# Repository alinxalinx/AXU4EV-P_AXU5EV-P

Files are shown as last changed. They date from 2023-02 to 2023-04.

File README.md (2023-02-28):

# Xilinx Zynq UltraScale+MPSoC series development board AXU4EV-P/AXU5EV-P
## Introduction to development board  
### Introduction to development board
In terms of backplane design, we have extended a variety of peripheral interfaces for users, such as one FMC LPC interface, one M.2 SSD SSD interface, one DP interface, one PCIE x2 interface, two SFP+optical fiber interfaces, four USB3.0 interfaces, two gigabit Ethernet interfaces, one HDMI input interface, one HDMI output interface, two UART interfaces, one SD card interface, two CAN bus interfaces 2-way RS485 interface and 1-way MIPI camera interface, etc.
### Key characteristics 
1. 1-way M.2 interface, PCIEx1 (ps), speed 6Gbps
2. 1-channel DP output interface, mini DP (ps), maximum support 4kx2k@30fps output
3. 4-way USB3.0 interface, usb (ps), speed 5.0Gbps, flat USB interface (USB Type A)
4. 2-way Gigabit Ethernet interface, jl2121, 1-way ps, 1-way pl, rgmii interface
5. Two uart to usb, one ps and one pl
6. 2-way PCIE3.0, PCIEx2 high-speed transmission interface, rate 8G Baud
7. 2-way SFP pipeline interface, 12.5Gb/s
8. 1 Micro SD card holder (ps)
9. One channel of hdmi video input interface and one channel of hdmi video output interface, with maximum support 1080P@60Hz resolving power
10. 1 standard FMC LPC expansion port
11. 2-way CAN communication interface (ps)
12. 2-way 485 communication interface (pl)
13. 1 channel mipi interface (pl), 15PIN FPC connector, 2 lane data, 1 pair of clock
14. 1 RTC real-time clock, 32.768KHz passive clock (ps)
15. EEPROM and temperature sensor, one EEPROM 4Kbit (2x256x8bit) (ps), one LM75 temperature chip (ps), with an accuracy of 0.5 degrees
16. 3 led lights, 1 power supply, 1 pl control, 1 ps control
17. 3 keys, 1 reset key RESET and 2 user keys
18. 200mmx110mm
19. 12v/3A

# AXU4EV-P/AXU5EV-P Demo Project
## Description
This is vivado factory demo project for ALINX board.
## Requirement
* Vivado 2020.1
* AXU4EV-P/AXU5EV-P Development Board
## Create Vivado Project
* Download recent release ZIP archive.
* Create new project folder.
* Extract the download ZIP to the new project folder.
* For different development board, please open **\<archive extracted location\>/vivado/auto_create_project/project_info.tcl**
Choose one devicePart and save.

xczu4ev-sfvc784-1-i is for AXU4EV-P  
xczu5ev-sfvc784-2-i is for AXU5EV-P  
```
set devicePart "xczu4ev-sfvc784-1-i"
#set devicePart "xczu5ev-sfvc784-2-i"
set runs_jobs 5
```

There are two methods to create vivado project as below:
### Create Vivado Project in Vivado tcl console
1. Open Vivado software and switch to "**auto_create_project**" path with **cd** command and **Enter**
```
cd \<archive extracted location\>/vivado/auto_create_project
```
2. Type **source ./create_project.tcl** and **Enter**
```
source ./create_project.tcl
```

### Create Vivado Project using bat
1. In "**auto_create_project**" folder, there is "**create_project.bat**", open it in edit mode, and change to your own vivado software installation path. Save and close.
```
CALL E:\XilinxVitis\Vivado\2020.1\bin\vivado.bat -mode batch -source create_project.tcl
PAUSE
```
2. Double click bat file in Windows environment

For more information, please post on the [ALINX Website] (https://www.alinx.com/en).

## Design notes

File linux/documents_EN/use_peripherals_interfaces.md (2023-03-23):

[Back to Home](../)
## Use the interfaces and peripherals on the development board in LINUX

---
- These interfaces and peripherals are available on the development board AXU4EV-P, AXU5EV-P:\
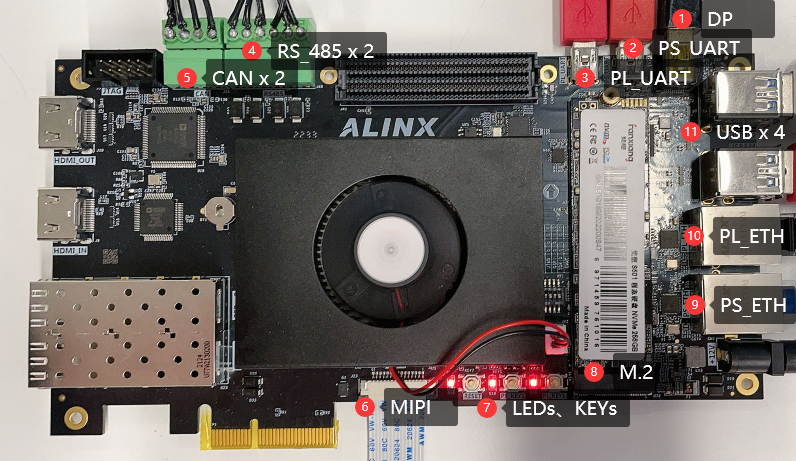
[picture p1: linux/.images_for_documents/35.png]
\
①DP\
②PS_UART\
③PL_UART\
④RS485 x 2\
⑤CAN x 2\
⑥MIPI\
⑦LEDS、KEYS\
⑧M.2\
⑨PS_ETH\
⑩PL_ETH\
⑪USB x 4\
⑫EMMC(Not visible in the figure)\
⑬EEPROM(Not visible in the figure)\
⑭QSPI FLASH(Not visible in the figure)\
⑮RTC(Not visible in the figure)\
⑯LM75(Not visible in the figure)\
PS：In the Linux system on the development board made earlier, I integrated some scripts in *~/shells_for_testing_peripheral_devices/* path which use to test these interfaces and peripherals. You can also refer to these scripts to use these interfaces and peripherals:\
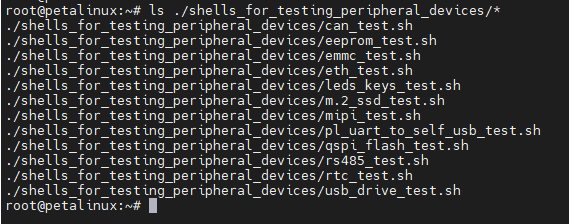
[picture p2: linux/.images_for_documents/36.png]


---
### ①DP
#### 1.1What is DP
DP (DisplayPort) interface is a digital video and audio interface standard used to connect computers, televisions, monitors, audio and other equipment. It is an open standard developed by Video Electronics Standards Association (VESA).\
There are two physical interfaces of DP interface, one is the standard DP interface in rectangular shape, and the other is the Mini DP interface in circular shape. The Mini DP interface is used on our development board.
#### 1.2Using DP in Linux
Connect DP to the display, and you can see the desktop of Macthbox after the system is started :\
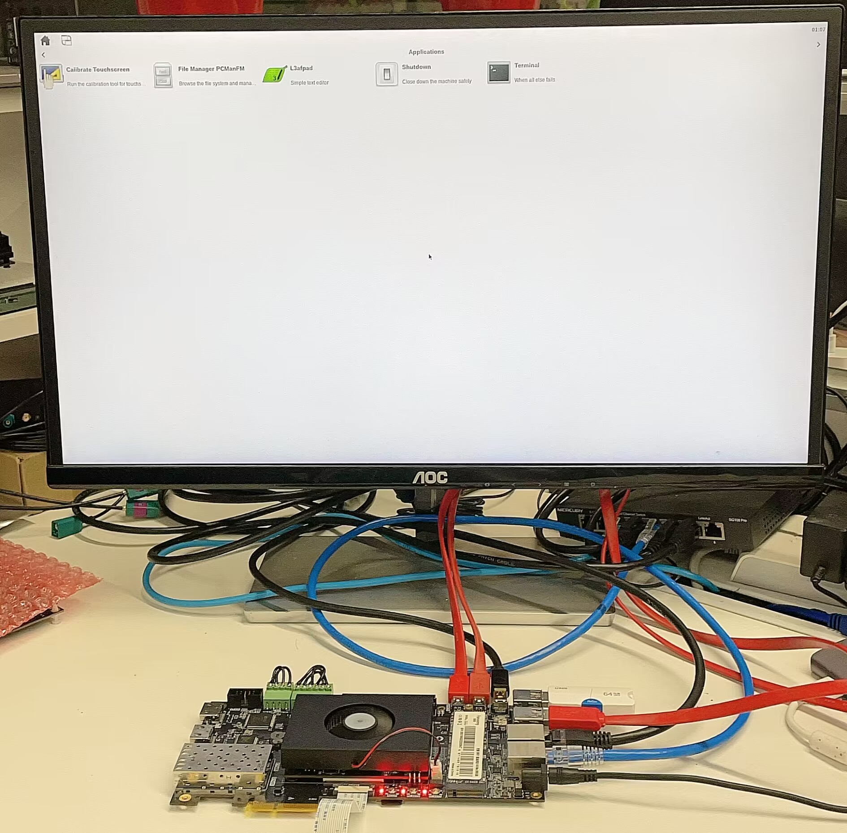
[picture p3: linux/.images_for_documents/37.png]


---
### ②PS_UART
#### 2.1What is PS_UART
UART is a communication protocol, which is called "Universal Asynchronous Receiver/Transmitter". It is a serial communication protocol that can be used to transmit data between microcontrollers, sensors, computer peripheral devices, communication devices, etc.\
UART uses two signal lines for data transmission: one is the data line (TX), which is responsible for sending data; The other is the receiving line (RX), which is responsible for receiving data. UART communication uses asynchronous transmission mode, that is, the clock signals of both sides of the communication are not synchronized, and the start bit, stop bit and parity bit need to be added in the data transmission to ensure the correctness of the data.\
The main advantages of UART are simple, flexible and widely used. Because it is a general protocol that can communicate between different devices, it is widely used in embedded systems and communication fields.\
PS_ UART is the UART interface of ARM end (also called PS end) in ZYNQMP chip.
#### 2.2Using PS_UART in Linux
PS_UART is used as the default terminal console for Linux in our system. Connect PS_UART to the PC(***The driver of CP210x needs to be installed on the PC***) :\
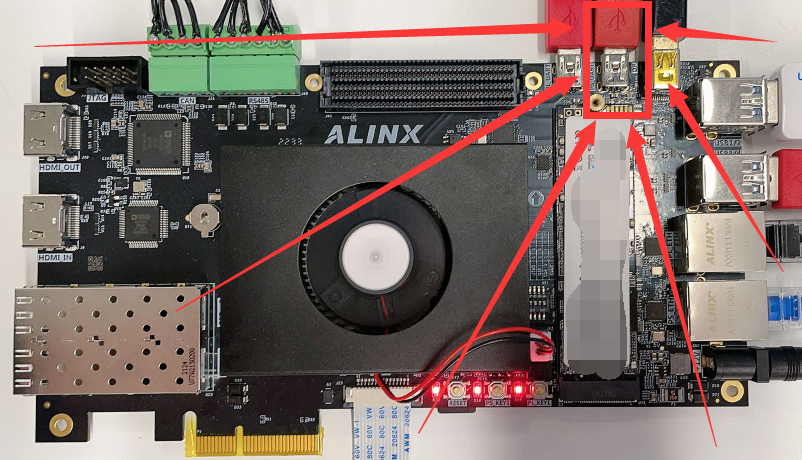
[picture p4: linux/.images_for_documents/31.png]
\
Open the corresponding COM with the serial port tool, set the baud rate to 115200, close the flow control, and click the OK button :\
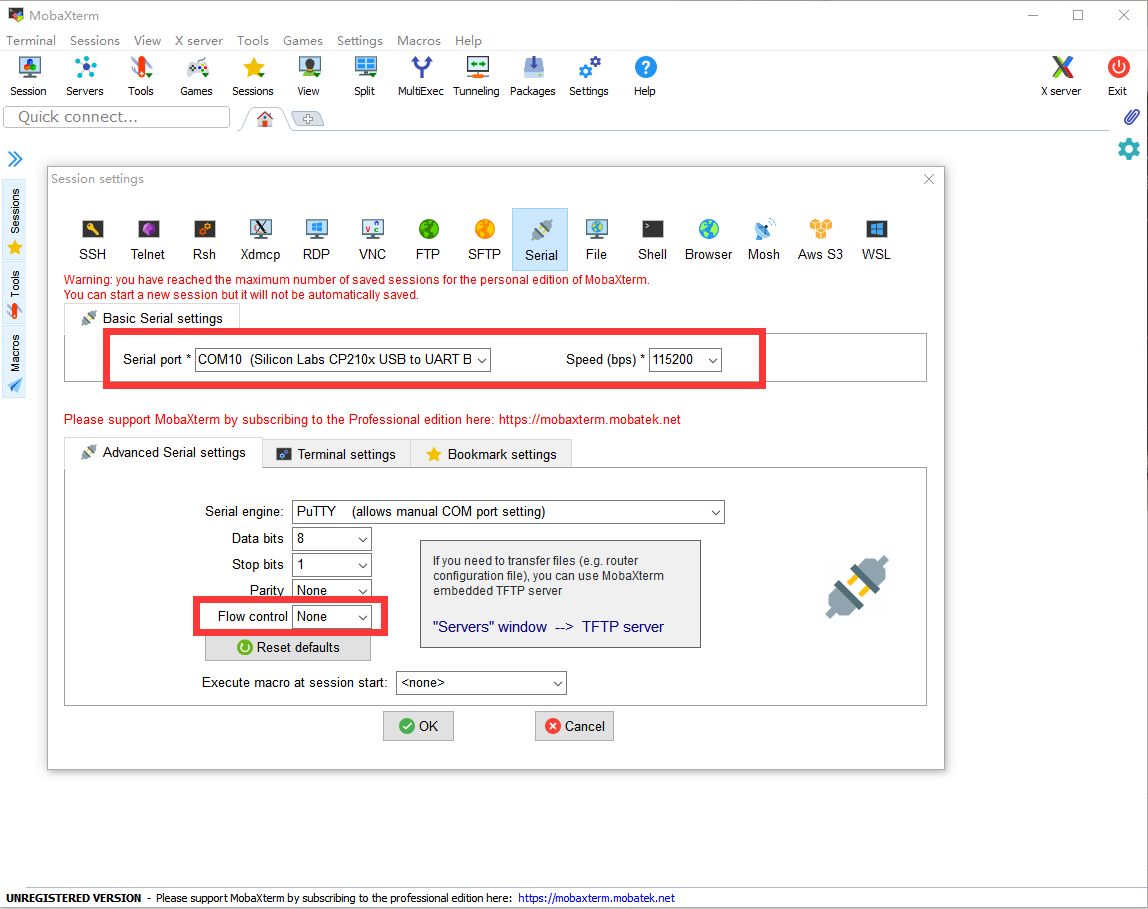
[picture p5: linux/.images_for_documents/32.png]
\
After starting the development board, you can see the print information in the serial port tool :\
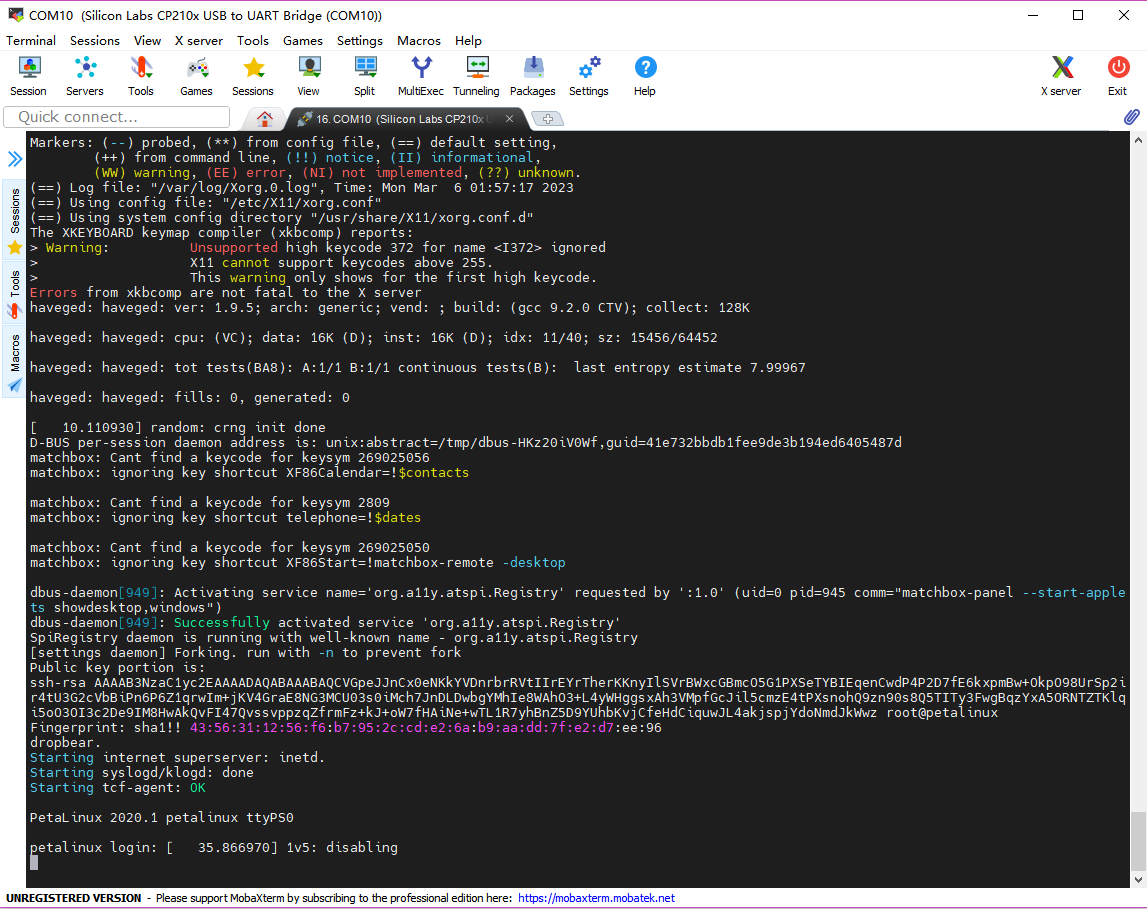
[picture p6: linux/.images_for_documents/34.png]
\
The device of PS_UART in our Linux system is */dev/ttyPS0*. You can use PS_UART interface transmits data by using the `echo "PS_UART test" > /dev/ttyPS0` command :\
\
You can see that the serial port has echo. But PS_UART is used for terminal console, so it is not recommended to operate */dev/ttyPS0*.

---
### ③PL_UART
#### 3.1What isPL_UART
PL_UART is different from PS_UART is the UART interface of the FPGA (also called PL) in the ZYNQMP chip.
#### 3.2Using PL_UART in Linux
Connect the PL_UART to the PC(***The driver of CP210x needs to be installed on the PC*** ).\
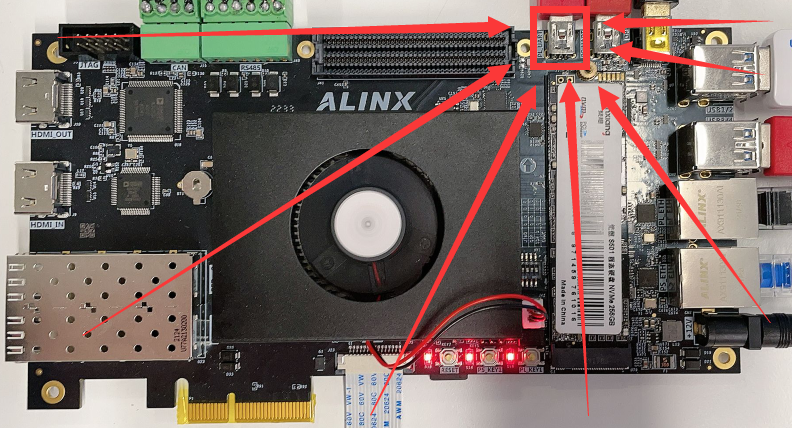
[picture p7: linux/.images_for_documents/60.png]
\
Open the serial port tool, select the corresponding COM, and set the baud rate to 115200 :\
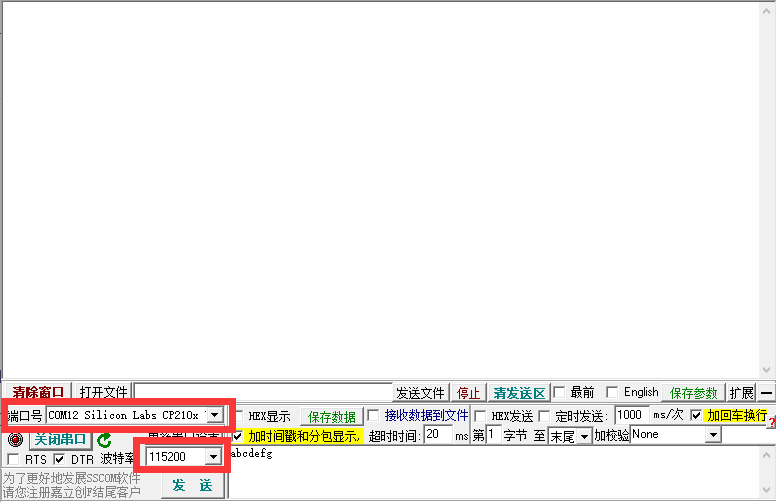
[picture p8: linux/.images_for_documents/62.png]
\
**The number of COM depends on your PC. If your PS_UART and PL_UART are all connected to PC, you can see at least two COM suffixes with *Silicon Labs CP210x USB to UART Bridge* :**\
\
In the Linux system of the development board, the PL_UART device is */dev/ttyPS3*, and the default baud rate is 9600. You can use this command to set the baud rate.\
`stty -F /dev/ttyPS3 ispeed 115200 ospeed 115200 cs8`\
We set it to 115200 corresponding to the setting of the serial port tool, and then use the following command to print the data received by UART :\
`cat /dev/ttyPS3`\
\
Then send some data in the serial port tool, and you can see that the system has received these data :\
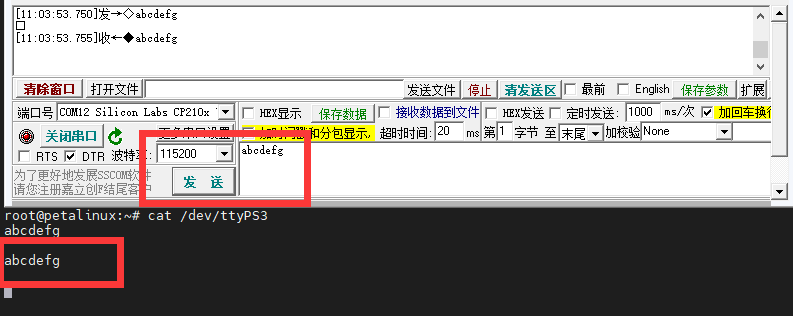
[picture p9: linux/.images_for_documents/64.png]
\
Press *ctrl c* on the keyboard to exit the *cat /dev/ttyPS3* command, and then use the following command to send data \"*PL_UART test*\" to the PC through PL_UART. The serial port tool can receive data:\
`echo "PL_UART test" > /dev/ttyPS3`\
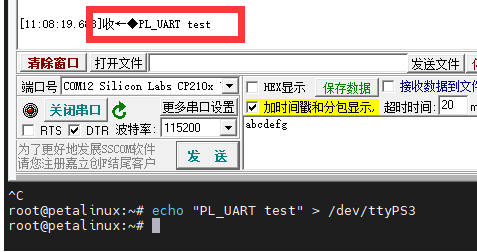
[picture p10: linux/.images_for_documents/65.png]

#### 3.3Use the built-in script in Linux to test PL_UART
Connect the PL_UART to any USB port on the development board :\
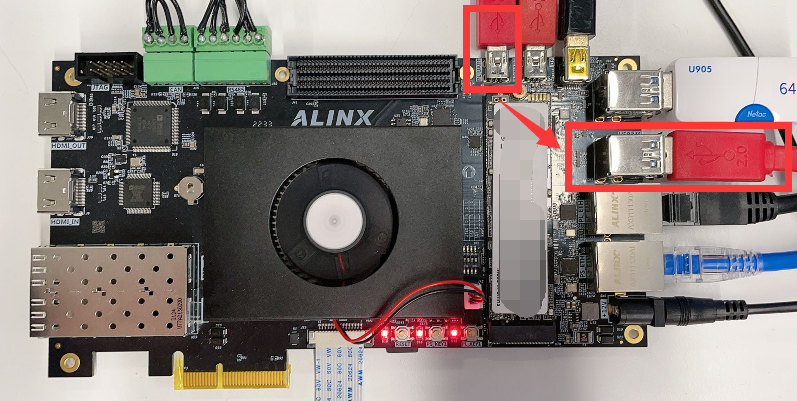
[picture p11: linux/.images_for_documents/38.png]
\
Run the *pl_uart_to_self_usb_test.sh*  script in *~/shells_for_testing_peripheral_devices/* :\
\
Output \"*pl uart to self usb test OK* \" indicates that the UART is intact(ps: this script also verifies that the USB interface is intact).

---
### ④RS485 x 2
#### 4.1What is RS485
RS485 is a common serial communication protocol, also known as EIA-485 protocol. It is a standard formulated by the American Electronic Industry Association (EIA), which is used for data communication between multiple devices. It can transmit data over a long distance. It has the characteristics of high-speed transmission and high reliability.\
RS485 can support point-to-point communication and multi-point communication between multiple devices, that is, a host can communicate with multiple slaves, and can also achieve communication between multiple slaves, to achieve a flexible network topology. The maximum transmission distance of RS485 can reach 1200 meters, and the transmission speed can reach 10 Mbps. In practical applications, the communication rate of 9600 bps or 115200 bps is usually used.\
In our development board, RS485 is a PL-end device, which is realized through FPGA IP.
#### 4.2Using RS485 in Linux
There are two RS485 channels on the development board. The corresponding device files in the system are */dev/ttyS1* and */dev/ttyS2*. RS485 equipment operates in the same way as PS_UART and PL_UART. However, it should be noted that the **baud rate of these two RS485 is fixed at 9600** due to the IP limit at the PL. Setting baud rate of these two RS485 to other values will prevent the device from working properly.
#### 4.3Use the built-in script in Linux to test RS485
Interconnect two RS485 channels：\
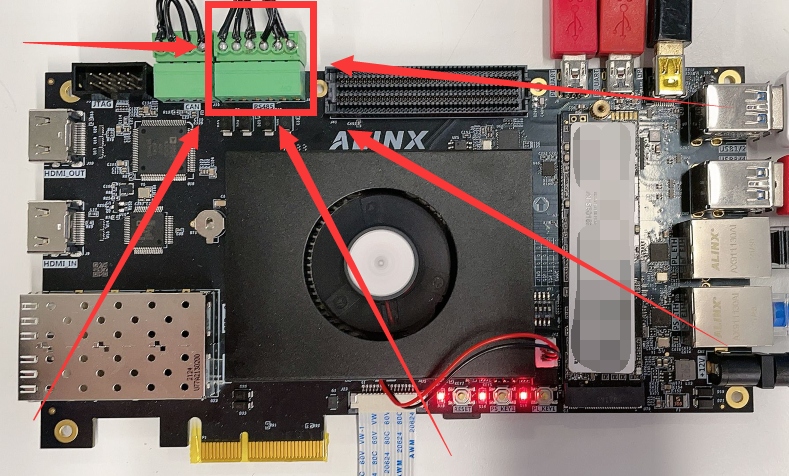
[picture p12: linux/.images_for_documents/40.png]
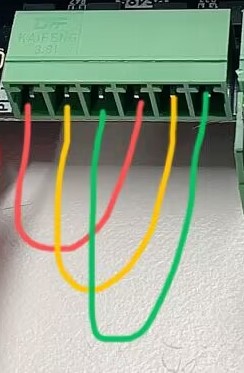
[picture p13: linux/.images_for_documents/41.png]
 \
Run the *rs485_test.sh* script in *~/shells_for_testing_peripheral_devices/* :\
\
As shown in the figure above, the two-way transceiver test is OK, the interface is intact.

---
### ⑤CAN x 2
#### 5.1What is CAN
CAN bus is a serial communication bus, which is a communication protocol widely used in automotive electronics, industrial control and robotics. CAN bus can support data communication between multiple nodes, which is efficient and reliable.\
In the CAN bus, each node can send and receive data, and the nodes are connected through the bus. CAN bus uses differential signal to transmit data, which can reduce the influence of electromagnetic interference and noise and improve the reliability of signal transmission.\
The data frame of CAN bus is divided into standard frame and extended frame. The standard frame contains 11-bit identifier and 8-byte data, while the extended frame contains 29-bit identifier and 8-byte data.\
In Linux system, the control and data transmission of CAN bus can be realized through Socket CAN interface.\
SocketCAN is an open source Linux kernel module, which provides the protocol stack and driver of the CAN bus, and provides a set of interfaces for user-level applications to control and transmit data on the CAN bus. The user can configure the CAN interface and set the parameters of the CAN bus through the ipconfig command.
#### 5.2Using CAN in Linux
Use the command \"`ifconfig - a`\" to see that there are two can channels on the development board, namely *can0* and *can1* :\
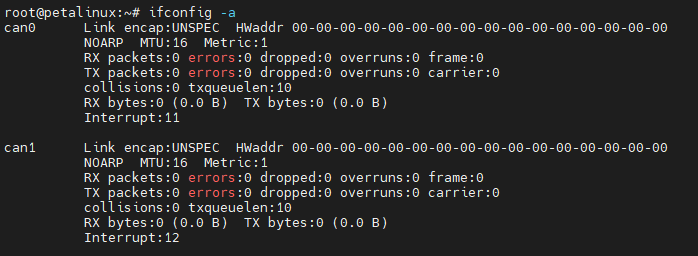
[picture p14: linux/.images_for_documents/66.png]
\
Use this command to set the bitrate of can0 and start can0 :\
`ip link set can0 up type can bitrate 1000000`\
Use this command to receive the data received by can0 :\
`candump can0`\
Use this command to send hex data \"11 22 33 44 55\" with id \"5A1\" via can0 to the CAN bus :\
`cansend can0 5A1#11.2233.4455`
#### 5.3Use the built-in script in Linux to test CAN
Interconnect the two CANs:\
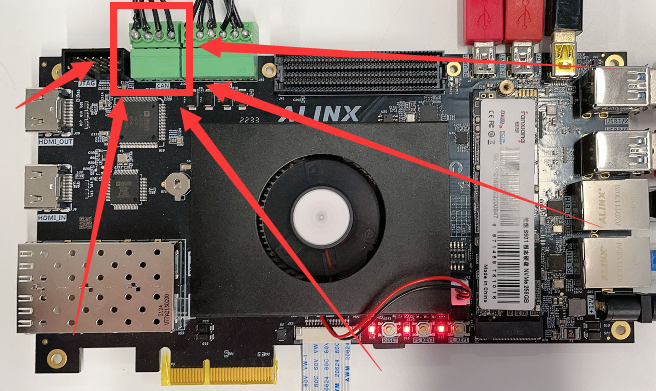
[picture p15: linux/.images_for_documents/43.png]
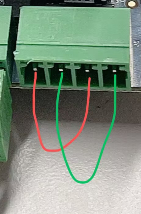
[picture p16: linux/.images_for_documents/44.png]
 \
Run the *can_test.sh* script in *~/shells_for_testing_peripheral_devices/* :\


---
### ⑥MIPI
#### 6.1What is MIPI
MIPI is the abbreviation of Mobile Industry Processor Interface. It is a series of interface standards developed by the MIPI Alliance, an organization created by some major mobile device manufacturers.\
MIPI is mainly committed to defining a series of hardware and software interface standards for mobile devices, including communication interfaces such as cameras, monitors and controllers, to help various parts of mobile devices exchange data and control signals more efficiently. MIPI protocol has the characteristics of high bandwidth, low power consumption, scalability, reliability and security, and is very suitable for modern mobile devices.\
In addition to mobile devices, the application of MIPI has also gradually expanded to other fields, such as automobiles, the Internet of Things, medical devices, etc., and has become one of the important interfaces for communication and control.\
In the current system of our development board, MIPI is designed as an input, which can be connected to the MIPI camera.
#### 6.2Using MIPI in Linux
First, connect a screen to the DP port and connect an OV5640 camera with a MIPI interface to development board(please do not operate with power) :\
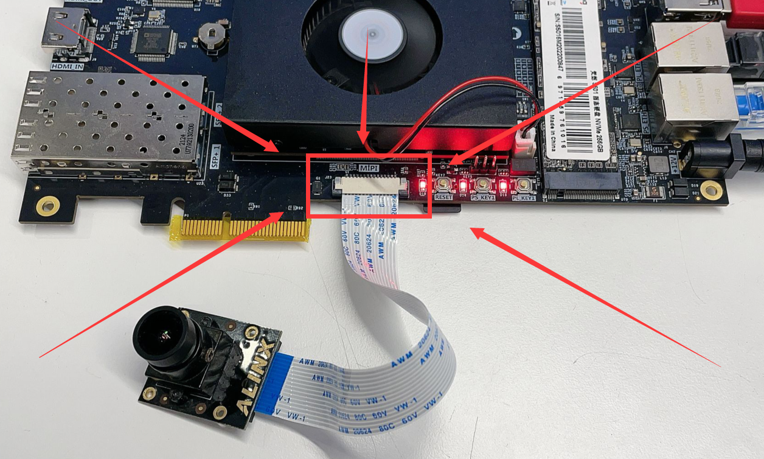
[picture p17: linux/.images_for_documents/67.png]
\
After the system is started and logged in, use the following command：\
`media-ctl -p -d /dev/media0`\
If the node information under the device can be obtained successfully, it means that the i2c connection of the device ov5640 is normal.\
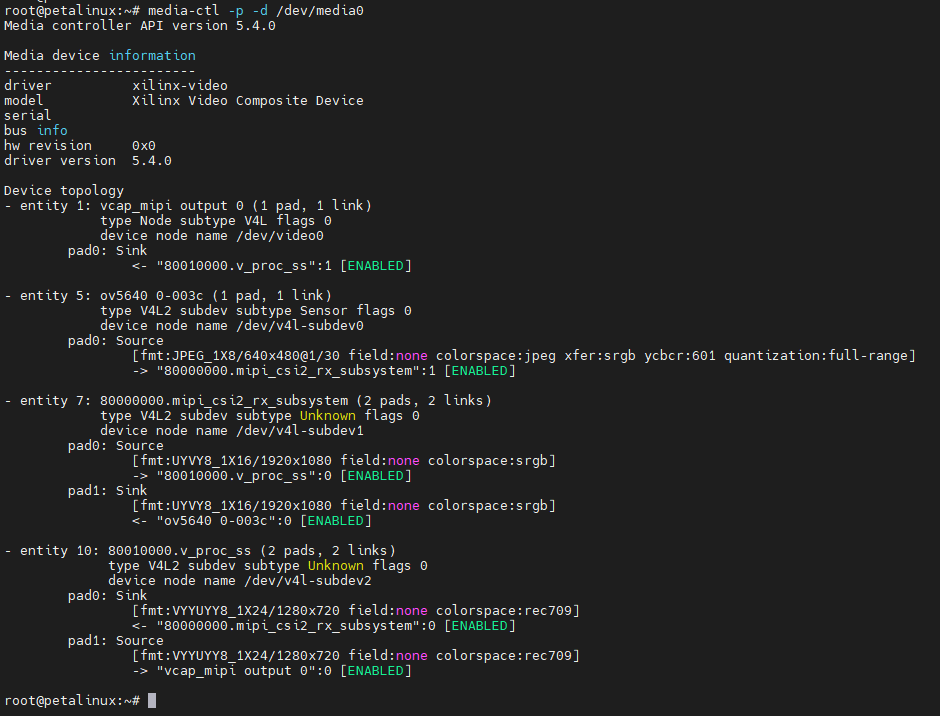
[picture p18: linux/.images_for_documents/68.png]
\
According to the above information, we can obtain the device node name as follows :
```
ov5640 0-003c
80000000.mipi_csi2_rx_subsystem
80010000.v_proc_ss
```
Use the following command to set the camera to 1920x1080, UYVY :
```
media-ctl -V '"ov5640 0-003c":0 [fmt:UYVY8_1X16/1920x1080@1/30 field:none]'
media-ctl -V '"80000000.mipi_csi2_rx_subsystem":0 [fmt:UYVY8_1X16/1920x1080 field:none]'
media-ctl -V '"80000000.mipi_csi2_rx_subsystem":1 [fmt:UYVY8_1X16/1920x1080 field:none]'
media-ctl -V '"80010000.v_proc_ss":0 [fmt:UYVY8_1X16/1920x1080 field:none]'
media-ctl -V '"80010000.v_proc_ss":1 [fmt:UYVY8_1X16/1920x1080 field:none]'
```
Then use the following command to display 1920x1080 camera image on the display :\
`gst-launch-1.0 -e v4l2src device=/dev/video0 ! video/x-raw,format=YUY2,width=1920,height=1080 ! kmssink bus-id=fd4a0000.zynqmp-display fullscreen-overlay=1`
#### 6.3Use the built-in script in Linux to test MIPI
Connect the display to the DP port, connect the MIPI camera to the MIPI port, run the *mipi_test.sh*  script in *~/shells_for_testing_peripheral_devices/* (*ps：Press **ctrl+c** to exit the script.*)：\
\
The camera image is displayed in the screen :\
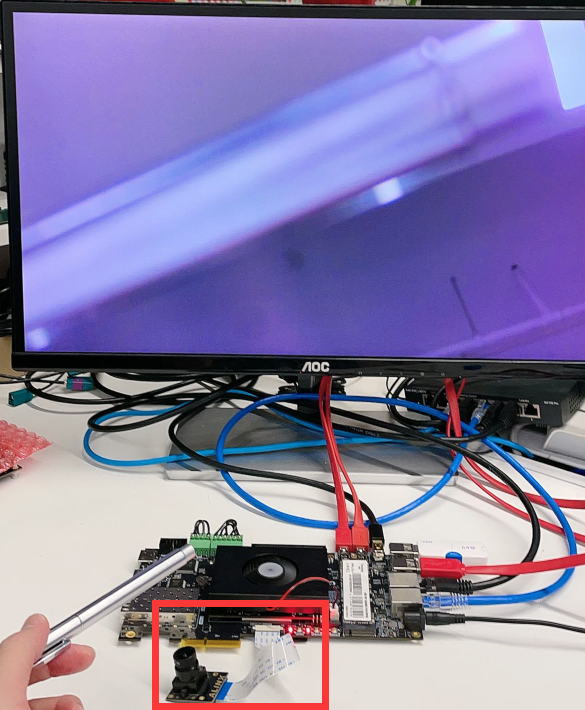
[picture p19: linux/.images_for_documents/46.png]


---
### ⑦LEDS、KEYS
#### 7.1LEDs and KEYs on the development board
There are three groups of LEDs and KEY on the development board. The first group is the POWER indicator and RESET button, the second group is the LED and KEY at the PS, and the third group is the LED and KEY at the PL. The POWER and PS_LED light up after power-on:\
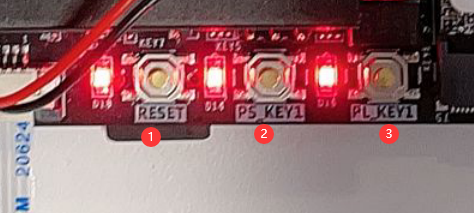
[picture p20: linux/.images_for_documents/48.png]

#### 7.2Using LEDs and KEYs in Linux
Using LEDs and KEYs is actually configuring and using GPIO. In Linux, you only need to know the GPIO number to use the corresponding IO port. The GPIO number of PS_LED is 373, the GPIO number of PS_KEY is 359, the GPIO number of PL_LED is 509, and the GPIO number of PL_KEY is 510.\
The IO corresponding to LED needs to be configured as output. Take PS_LED as an example, the steps to use GPIO output are as follows :
```
#Export the corresponding port
echo 373 >> /sys/class/gpio/export
#Set this port as output
echo out >> /sys/class/gpio/gpio373/direction
#Make this port output high level and light LED
echo 1 >> /sys/class/gpio/gpio373/value
#Make this port output low level and turn off LED
echo 0 >> /sys/class/gpio/gpio373/value
```
The IO corresponding to KEY needs to be configured as output. Taking PL_KEY as an example, the steps to use GPIO input are as follows :
```
#Export the corresponding port
echo 510 >> /sys/class/gpio/export
#Set this port as input
echo in >> /sys/class/gpio/gpio510/direction
#Read the current level state of this IO
cat /sys/class/gpio/gpio510/value
```

#### 7.3Use the built-in script in Linux to test LEDs and KEYs
Run the *leds_keys_test.sh* script in *~/shells_for_testing_peripheral_devices/* (*ps：Press **ctrl+c** to exit the script.*). Then you can use PS_KEY to control the PS_LED to turn on and off, and PL_KEY to control the PS_LED to turn on and off :\


---
### ⑧M.2
#### 8.1What is M.2
M.2 is a high-speed, low-power interface for connecting external devices, such as solid-state hard disk, NVMe devices, etc.\
M.2 Interface consists of PCI Express (PCIe) and SATA (Serial ATA) protocols, which can be used for data transmission, storage and communication. PCIe protocol provides faster transmission speed and more bandwidth, while SATA protocol is more suitable for low-power and high-capacity storage devices.
#### 8.2Use M.2 interface in the system
Take SSD equipment as an example, connect SSD on the M.2 interface of the development board (please do not operate with power) :\
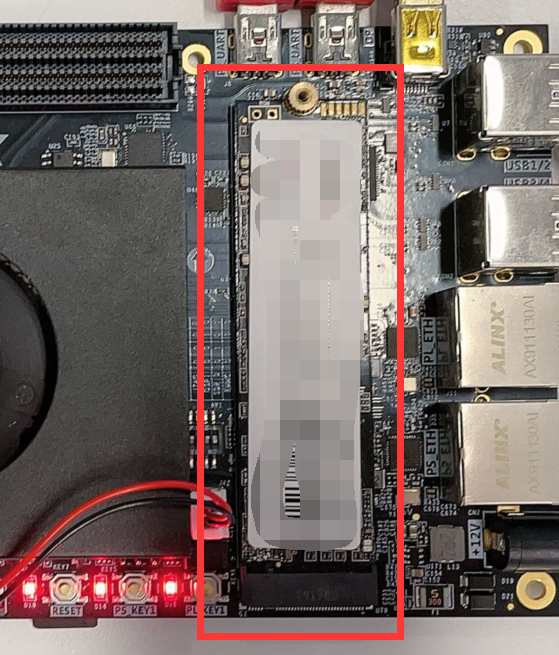
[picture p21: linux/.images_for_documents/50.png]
\
Then start the development board and log in to Linux. If you can find */dev/nvme0n1*, it means that the SSD has been successfully recognized.\
If this SSD has been partitioned, you can also find the device operation files corresponding to partitions like */dev/nvme0n1p1*, */dev/nvme0n1p2* and so on.\
If the SSD does not have a partition or the file system format of the partition is not supported by the Linux system, you can use the **fdisk** tool to allocate the partition, use the **mkfs** tool to set the file system formart, and use the **mount** command to mount it.
For example, the following command will delete the first partition of  */dev/nvme0n1*  and create a new partition, then format the partition into ext4 and mount it to */run/media/nvme0n1p1* :\
```
#Unmount partition
umount /dev/nvme0n1p1
#Delete a partition of /dev/nvme0n1 and create a new partition
echo "d

n
p
1

w
" | fdisk /dev/nvme0n1
#Format the /dev/nvme0n1p1 partition into ext4
echo "y

" | mkfs.ext4 /dev/nvme0n1p1
#mount /dev/nvme0n1p1 on /run/media/nvme0n1p1
mount /dev/nvme0n1p1 /run/media/nvme0n1p1
```
After mounting, you can operate on files in the mounted path, and these files will eventually be saved in the SSD.
#### 8.3Use the built-in script in Linux to test M.2 SSD
Run the *m.2_ssd_test.sh*  script in *~/shells_for_testing_peripheral_devices/* :\
\
Different information will be printed according to the usage of your SSD, but as long as the M.2 interface and SSD are intact, \"*ssd read write OK* \" will be output.

---
### ⑨PS_ETH
#### 9.1What is ETH
In the Linux operating system, \"ETH\" usually refers to the network interface device, which is the hardware device used to communicate between the computer and the network. In Linux, you can use the *ifconfig* command to manage and configure network interface devices. The development board and other network devices can be connected in the same network through the ETH interface for data transmission.\
In the Ethernet protocol, each device is assigned a unique MAC address for identification and communication in the network. When computers send data through network interface devices, they will be encapsulated in Ethernet frames and routed and transmitted using MAC addresses.\
The PS_ETH on the development board is the ETH on the PS side, and the PS_ETH is the ETH on the PL side implemented by IP, but their use methods are the same in the system.
#### 9.2Using ETH in Linux
Connect PS_ETH and PL_ETH (such as through network router or network switch) to the LAN :\
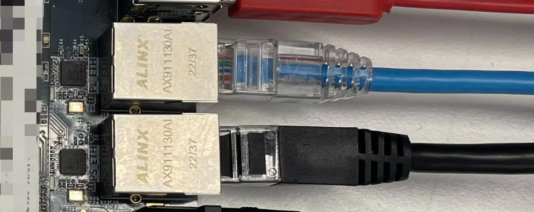
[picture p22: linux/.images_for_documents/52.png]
\
Then power on the development board, log in to the system, and use *ifconfig* to view the current ETH status :\
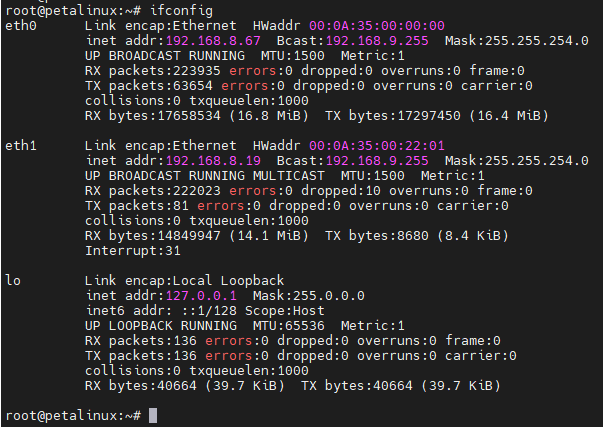
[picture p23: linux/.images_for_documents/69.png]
\
If your router or switch supports DHCP, both eth0 and eth1 will be automatically connected and be assigned an IP address.\
If no IP address is assigned, you need to use the following command to assign it manually, for example :\
`ifconfig eth0 192.168.8.67`\
The *ifconfig* command can also be used to set the subnet mask; If the MAC address needs to be modified, */etc/network/interfaces* needs to be modified; If you want to set the gateway, you need to use command **route**; If you need to modify DNS, you need to modify */etc/resolv.conf*. The relevant configuration will not be detailed, generally, as long as you connect to the LAN through the network cable, you can use eth0 directly after the system is powered on.\
If you want to use eth1, you need to set the default gateway of eth1. The address of the gateway depends on your LAN. If your eth1 and eth0 are connected to the same segment of the same LAN, you can refer to the settings of eth0, for example :
```
#Use route to view the gateway of eth0 first
route
#Set the default gateway of eth1 to be the same as eth0. For example the above route command shows that the default gateway of eth0 is 192.168.8.1
route add default gw 192.168.8.1 eth1
#Use the route command to check and confirm the default gateway of eth1
route
```
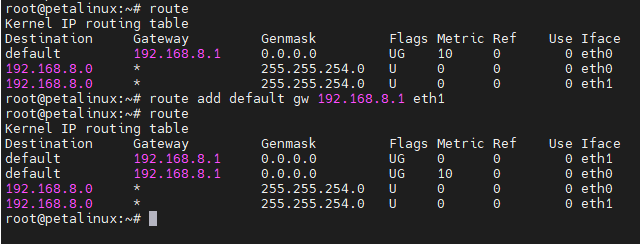
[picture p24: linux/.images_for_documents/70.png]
\
You can use the **ping** command to test the network connection and disconnection, set the number of pings through the **-c** parameter, and select the network interface through the **-I**(uppercase i) parameter :\
`ping -c 1 -I eth1 www.baidu.com`\

#### 9.3Use the built-in script in Linux to test ETH
Run the *eth_test.sh*  script in *~/shells_for_testing_peripheral_devices/*. This script can be followed by a parameter, that is, the address you want to ping. For example, here I ping www.baidu.com. If no parameter is added, the default is ping *www.google.com* :\
\
Finally, the result of the ping and the speed of the network interface link will be print.

---
### ⑩PL_ETH
**See ⑨PS_ETH**.

---
### ⑪USB x 4
#### 11.1What is USB
USB is the abbreviation of Universal Serial Bus. It is a universal data transmission standard used to connect computers or other devices with other devices, including printers, keyboards, mice, scanners, digital cameras, mobile devices and other external devices.\
With the continuous development of technology, the version of USB is also constantly updated. USB 1.0 is the earliest version and the transmission speed is very slow, but with the introduction of USB 2.0, the transmission speed has been significantly improved. USB 3.0 and USB 3.1 are faster versions, providing higher transmission speed and more power. At the same time, USB can also support different data transmission protocols, including HID (human interface device), audio, video and storage devices.\
There are four USB3.0 interfaces on our development board.
#### 11.2Using USB on Linux systems
In fact, common USB devices can be used directly on this system. For example, the mouse and keyboard can be used directly with the desktop. If you use the storage tools such as USB flash disk, you need to pay attention to the partition and file system format. You can refer to the partition and format method of SSD in **⑧M.2**. After the USB flash disk is connected to the system, the device operation files are generally */dev/sda1*, */dev/sda2*, etc.
#### 11.3Use the built-in script in Linux to test USB Drive
Run the *usb_drive_test.sh*  script in *~/shells_for_testing_peripheral_devices/* ( *ps：This system does not support the NTFS file system, so the USB flash drive of the NTFS partition cannot be used directly* ) :\


---
### ⑫EMMC
#### 12.1What is EMMC
EMMC (Embedded MultiMediaCard) is a storage device widely used by embedded devices. It integrates flash memory chip, controller, host interface and flash memory management software into a small package. With its small size, low power consumption and high cost performance, eMMC is a common choice in embedded device storage solutions.\
EMMC is mainly used in mobile devices (such as smart phones, tablets, digital cameras, etc.) and embedded devices in automotive, industrial control and other fields. It provides a high-speed and reliable storage solution, supports fast startup and data reading and writing, and can store operating system, application programs, media files and other data.\
An 8G EMMC is integrated on our development board.
#### 12.2Using EMMC on Linux
The operation file of EMMC in Linux system is */dev/mmcblk0*. The use method is similar to that of SSD in **⑧M.2** : set the partition, format the partition, and finally mount the partition. for example :
```
#Unmount partition
umount /dev/mmcblk0p1
#Delete a partition of /dev/mmcblk0 and create a new partition
echo "d

n
p
1

w
" | fdisk /dev/mmcblk0
#Format the /dev/mmcblk0p1 partition into ext4 format
echo "y

" | mkfs.ext4 /dev/mmcblk0p1
#mount /dev/mmcblk0p1 on /media/sd-mmcblk0p1
mount /dev/mmcblk0p1 /media/sd-mmcblk0p1
```
After mounting, you can operate on files in the mounted path, and these files will eventually be saved in EMMC.
#### 12.3Use the built-in script in Linux to test EMMC
Run the *emmc_test.sh* script in *~/shells_for_testing_peripheral_devices/*  :\


---
### ⑬EEPROM
#### 13.1What is EEPROM
EEPROM is a non-volatile memory (NVM), which is an improved version of the electrically erasable programmable read-only memory (EPROM). EEPROM can be erased and programmed by electronic signals.\
EEPROM is usually used to store a small amount of data, such as configuration information on the chip, product serial number, encryption key, etc. In some electronic devices, EEPROM can also be used to store user settings and personal data.\
Compared with flash memory, EEPROM has faster reading speed and higher durability, but smaller capacity. Compared with DRAM, EEPROM has longer data retention time, but slower write speed.
#### 13.2Using EEPROM on Linux
The operating file of eeprom in the system is */sys/bus/i2c/devices/1-0050/eeprom*.\
Use the following command to write data to eeprom :\
`echo -e "test e2prom\n" > /sys/bus/i2c/devices/1-0050/eeprom`\
Use the following command to view the contents of eeprom :\
`cat /sys/bus/i2c/devices/1-0050/eeprom`\

#### 13.3Use the built-in script in Linux to test EEPROM
Run the *eeprom_test.sh* script in *~/shells_for_testing_peripheral_devices/*  :\


---
### ⑭QSPI FLASH
#### 14.1What is QSPI FLASH
Flash is a kind of high-speed flash memory, which is often used in embedded systems and other applications to store program code, configuration data and other information.\
QSPI Flash is a flash chip based on SPI interface. It communicates through four parallel data lines (quad interfaces). Compared with traditional SPI Flash, it can achieve faster data transmission speed, usually up to tens of MHz. The capacity of QSPI Flash is usually between a few megabytes and tens of megabytes.\
QSPI Flash has many advantages, including fast read and write speed, low power consumption, erasability, easy integration and use, etc. In addition, it can be programmed and erased by software without any external equipment or signal line.
#### 14.2Using QSPI FLASH on Linux systems
In the current Linux system, QSPI FLASH is used to store the environment variables of u-boot. If you modify the environment variables of u-boot, you need to be careful when operating QSPI FLASH.
The operation file of QSPI FLASH in the system is */dev/mtd0*.
The FLASH device needs to be erased before writing. Use the following command to erase the first sector of QSPI FLASH :\
`flash_erase /dev/mtd0 0 1`\
*/dev/mtd0* is a block device. You can use the **dd** command to read or write files to */dev/mtd0*.\
Write the file to */dev/mtd0 with the following command* :
```
touch /home/root/.qspiflashwrite
echo "qspiflash test" > /home/root/.qspiflashwrite
dd of=/dev/mtd0 if=/home/root/.qspiflashwrite bs=4096 count=1
```
Use the following command to read data from */dev/mtd0* to a file :
```
touch /home/root/.qspiflashread
dd if=/dev/mtd0 of=/home/root/.qspiflashread  bs=4096 count=1
```
#### 14.3Use the built-in script in Linux to test QSPI FLASH
Run the *qspi_flash_test.sh* script in *~/shells_for_testing_peripheral_devices/*  :\


---
### ⑮RTC
#### 15.1What is RTC
The Real Time Clock (RTC) unit provides an accurate time reference for the entire system and application software.
#### 15.2Using RTC on Linux systems
In our Linux system, the device operation file of RTC is */dev/rtc0*. You can use the **hwclock** command to read and write */dev/rtc0*. For example:
```
#Set the system time to "2023-03-01 10:30:00"
date --set="2023-03-01 10:30:00"
#Write the system time to/dev/rtc0
hwclock -f /dev/rtc0 -w
#Update the system time with the time in /dev/rtc0
hwclock -f /dev/rtc0 -r
```

#### 15.3Use the built-in script in Linux to test RTC
Run the *rtc_test.sh* script in *~/shells_for_testing_peripheral_devices/* :\


---
### ⑯LM75
#### 16.1What is LM75
LM75 is a digital temperature sensor chip produced by Texas Instruments. It can measure the ambient temperature and communicate with other devices through I2C bus. It is a digital temperature sensor chip with stable performance, high accuracy and good reliability.
#### 16.2Using LM75 on Linux systems
The temperature value collected by LM75 can be obtained by directly reading */sys/bus/i2c/devices/1-0048/hwmon/hwmon0/temp1_input* in Linux, **the unit of this data is m°C**:\
`cat /sys/bus/i2c/devices/1-0048/hwmon/hwmon0/temp1_input`\
\
The temperature read here is 31750m°C, equal to 31.75°C.

---
---
- Visit [ALINX official website](https://www.alinx.com) for more information.

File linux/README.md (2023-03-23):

# Run Linux on Series Development Boards : AXU4EV-P, AXU5EV-P / 在系列开发板：AXU4EV-P、AXU5EV-P上使用Linux
---
---
## Content in this path / 本路径中的内容 
	│
	└─── linux
		│
		├── hardware
		│	│
		│	├── AXU4EV-P
		│	│	│
		│	│	└─ design_1_wrapper.xsa	
		│	│
		│	└── AXU5EV-P
		│		│	
		│	 	└─ design_1_wrapper.xsa	
		│
		├── petalinux
		│
		├── documents_EN
		│	│
		│	├──  make_sd_for_runnging_linux.md	
		│	│
		│	├──  use_petalinux_to_make_linux.md	
		│	│
		│	└──  use_peripherals_interfaces.md
		│
		├── documents_CN
		│	│
		│	├──  make_sd_for_runnging_linux.md	
		│	│
		│	├──  use_petalinux_to_make_linux.md
		│	│
		│	└──  use_peripherals_interfaces.md
		│
		├── auto_config_petalinux_hardware.sh
		│
		├── set_offline_sstate_and_downloads.sh
		│
		└── README.md
---
---
## Documentation Guidelines
- If you want to quickly start a Linux on the development board, please refer to [make_sd_for_runnging_linux.md](./documents_EN/make_sd_for_runnging_linux.md).
- If you want to use Petalinux tool to configure the petalinux project we provide, please refer to [use_petalinux_to_make_linux.md](./documents_EN/use_petalinux_to_make_linux.md).
- If you have successfully started Linux on the development board, and now want to know what interfaces are on the development board and how to use them, please refer to [use_peripherals_interfaces.md](./documents_EN/use_peripherals_interfaces.md).
## 文档指引
- 如果你想快速在开发板上启动Linux，请参考[make_sd_for_runnging_linux.md](./documents_CN/make_sd_for_runnging_linux.md)。
- 如果你想用Petalinux工具来配置我们提供的petalinux工程，请参考[use_petalinux_to_make_linux.md](./documents_CN/use_petalinux_to_make_linux.md)。
- 如果你已经成功在开发板上启动了Linux，现在想知道开发板上有哪些接口以及如何使用，请参考[use_peripherals_interfaces.md](./documents_CN/use_peripherals_interfaces.md)。
---
---
- Visit [ALINX Official Website](https://www.alinx.com) for more information.
- 访问[ALINX官方网站](https://www.alinx.com)以获取更多信息。

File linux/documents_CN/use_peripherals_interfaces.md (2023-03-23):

[返回首页](../)
## 在LINUX中使用开发板上的接口和外设

---
- AXU4EV-P、AXU5EV-P开发板上有这些接口和外设：\
\
①DP\
②PS_UART\
③PL_UART\
④RS485 x 2\
⑤CAN x 2\
⑥MIPI\
⑦LEDS、KEYS\
⑧M.2\
⑨PS_ETH\
⑩PL_ETH\
⑪USB x 4\
⑫EMMC(图中不可见)\
⑬EEPROM(图中不可见)\
⑭QSPI FLASH(图中不可见)\
⑮RTC(图中不可见)\
⑯LM75(图中不可见)\
PS：在前面制作的开发板上的Linux系统中，我集成了一些脚本在 *~/shells_for_testing_peripheral_devices/* 路径中用于测试这些接口和外设，你也可以参考这些脚本来使用这些接口和外设：\


---
### ①DP
#### 1.1什么是DP
DP (DisplayPort) 接口是一种数字视频和音频接口标准，用于连接计算机、电视、显示器、音响等设备。它是一种开放标准，由 Video Electronics Standards Association (VESA) 组织制定。\
DP 接口的物理接口有两种，一种是矩形形状的标准 DP 接口，另一种是圆形形状的 Mini DP 接口。我们的开发板上使用的就是Mini DP接口。
#### 1.2在Linux中使用DP
把DP连接到显示器上即可，系统启动后可以看到Macthbox的桌面：\

### ②PS_UART
#### 2.1什么是PS_UART
UART是一种通信协议，全称为“通用异步收发传输器”（Universal Asynchronous Receiver/Transmitter）。它是一种串行通信协议，可以用于在微控制器、传感器、电脑周边设备、通信设备等之间传输数据。\
UART使用两根信号线来进行数据传输：一根是数据线（TX），负责发送数据；另一根是接收线（RX），负责接收数据。UART通信使用异步传输方式，也就是说，通信双方的时钟信号不同步，需要在数据传输中加入起始位、停止位和奇偶校验位来保证数据的正确性。\
UART的主要优点是简单、灵活和广泛使用。由于它是一种通用协议，可以在各种不同的设备之间进行通信，因此在嵌入式系统和通信领域中应用广泛。\
PS_UART是ZYNQMP芯片中ARM端(也叫做PS端)的UART接口。
#### 2.2在Linux中使用PS_UART
PS_UART在我们制作的系统中用于Linux的默认终端窗口，把PS_UART连接到PC(***PC上需要安装CP210x的驱动***)：\
\
用串口工具打开对应的COM，设置波特率设置为115200，关闭流控制，点击OK按钮：\
\
启动开发板后可以看到串口工具中打印信息：\
\
PS_UART在我们制作的Linux系统中的设备是 */dev/ttyPS0* ，使用`echo "PS_UART test" > /dev/ttyPS0`命令可以通过PS_UART接口传输数据：\
\
可以看到串口有回显，但是PS_UART被用于终端窗口，因此不建议对 */dev/ttyPS0* 进行操作。

---
### ③PL_UART
#### 3.1什么是PL_UART
PL_UART区别于PS_UART，是ZYNQMP芯片中FPGA端(也叫做PL端)的UART接口。
#### 3.2在Linux中使用PL_UART
把PL_UART连接到PC(***PC上需要安装CP210x的驱动***)：\
\
打开串口工具，选择对应COM，波特率设置为115200：\
\
**COM的编号取决于你的PC，如果此时你的PS_UART和PL_UART都接在PC上，那么至少能看到两个后缀是*Silicon Labs CP210x USB to UART Bridge* 的COM：**\
\
在开发板的Linux系统中PL_UART设备是 */dev/ttyPS3*，默认波特率是9600，可以用这个命令来设置波特率：\
`stty -F /dev/ttyPS3 ispeed 115200 ospeed 115200 cs8`\
我们把它设置成115200和串口工具的设置对应，然后使用命令：\
`cat /dev/ttyPS3`\
来显示PL_UART收到的数据：\
\
在串口工具中发送一些数据，可以看到系统中收到了这些数据：\
\
在键盘上按*ctrl c*退出*cat /dev/ttyPS3*命令，然后用命令：\
`echo "PL_UART test" > /dev/ttyPS3`\
通过PL_UART发送数据*PL_UART test* 到PC，PC上串口工具可以收到数据：\

#### 3.3使用系统内置的脚本测试PL_UART
把PL_UART连接到开发板的任意一个USB口上：\
\
运行 *~/shells_for_testing_peripheral_devices/* 中的 *pl_uart_to_self_usb_test.sh* 脚本：\
\
输出\"*pl uart to self usb test OK* \"说明PL_UART完好(ps：这个脚本同时也验证了USB接口完好)。

---
### ④RS485 x 2
#### 4.1什么是RS485
RS485是一种常用的串行通信协议，也称为EIA-485协议。它是由美国电子工业协会（EIA）制定的标准，用于在多个设备之间进行数据通信，可以在较长的距离范围内传输数据，具有高速传输和高可靠性的特点。\
RS485可以支持多个设备之间的点对点通信和多点通信，即一个主机可以与多个从机进行通信，也可以实现多个从机之间的通信，实现灵活的网络拓扑结构。RS485的传输距离最远可以达到1200米，传输速度可以达到10Mbps，在实际应用中，通常采用的是9600bps或者115200bps的通信速率。\
在我们的开发板中RS485是PL端的设备，是通过FPGA的IP实现的。
#### 4.2在Linux中使用RS485
开发板上有两路RS485，在系统中对应的设备文件是 */dev/ttyS1* 和 */dev/ttyS2* 。**RS485设备的操作方式和UART相同**。但需要注意，由于PL端IP的限制，这两个RS485的波特率固定为9600，设置成其他值会使设备无法正常工作。
#### 4.3使用系统内置的脚本测试RS485
把两路RS485互联：\
 \
运行 *~/shells_for_testing_peripheral_devices/* 中的 *rs485_test.sh* 脚本：\
\
如上图所示，双向收发测试OK，接口完好。

---
### ⑤CAN x 2
#### 5.1什么是CAN
CAN总线是一种串行通信总线，它是一种广泛应用于汽车电子、工业控制和机器人等领域的通信协议。CAN总线能够支持多个节点之间的数据通信，具有高效、可靠的特点。\
在CAN总线中，每个节点都可以发送和接收数据，节点之间通过总线连接。CAN总线采用差分信号的方式传输数据，这种方式可以减少电磁干扰和噪声的影响，提高信号传输的可靠性。\
CAN总线的数据帧分为标准帧和扩展帧两种类型。标准帧包含11位标识符和8个字节的数据，扩展帧则包含29位标识符和8个字节的数据。\
在Linux系统中，可以通过SocketCAN接口来实现对CAN总线的控制和数据传输。\
SocketCAN是一个开源的Linux内核模块，它提供了CAN总线的协议栈和驱动程序，并为用户层应用程序提供了一组接口，以便对CAN总线进行控制和数据传输。用户可以通过ipconfig命令来配置CAN接口和设置CAN总线的参数。\
#### 5.2在Linux中使用CAN
使用`ifconfig -a`命令可以看到开发板上有两路can即*can0* 和*can1* ：\
\
使用这条命令来设置can0的bitrate并启动can0：\
`ip link set can0 up type can bitrate 1000000`\
使用这条命令可以接收can0收到的数据：\
`candump can0`\
使用这条命令可以通过can0发送id为\"5A1\"的十六进制数据\"11 22 33 44 55\"到CAN总线上：\
`cansend can0 5A1#11.2233.4455`
#### 5.3使用系统内置的脚本测试CAN
把两路can互联：\
 \
运行 *~/shells_for_testing_peripheral_devices/* 中的 *can_test.sh* 脚本：\


---
### ⑥MIPI
#### 6.1什么是MIPI
MIPI是移动行业处理器接口(Mobile Industry Processor Interface)的缩写，是由一些主要移动设备制造商创建的组织MIPI联盟所制定的一系列接口标准。\
MIPI主要致力于定义一系列用于移动设备的硬件和软件接口标准，包括像相机、显示器、控制器等通信接口，以帮助移动设备的各个部分之间更高效地交换数据和控制信号。MIPI协议具有高带宽、低功耗、可扩展性、可靠性和安全性等特点，非常适用于现代移动设备。\
除了移动设备，MIPI的应用还逐渐扩展到了其他领域，如汽车、物联网、医疗设备等，成为了通信和控制的重要接口之一。\
我们开发版当前系统的系统中MIPI被设计成了输入，可以连接MIPI摄像头使用。
#### 6.2在Linux中使用MIPI
首先我们连接显示器到DP口并接入一个MIPI接口的OV5640摄像头(请不要带电操作)：\
\
在系统启动并登录后使用命令：\
`media-ctl -p -d /dev/media0`\
如果可以成功获取设备下各节点信息，则说明设备ov5640的i2c连接正常。\
\
根据上面的信息，我们可以获取到设备节点名如下：
```
ov5640 0-003c
80000000.mipi_csi2_rx_subsystem
80010000.v_proc_ss
```
使用下面的命令设置摄像头为1920x1080、UYVY格式：
```
media-ctl -V '"ov5640 0-003c":0 [fmt:UYVY8_1X16/1920x1080@1/30 field:none]'
media-ctl -V '"80000000.mipi_csi2_rx_subsystem":0 [fmt:UYVY8_1X16/1920x1080 field:none]'
media-ctl -V '"80000000.mipi_csi2_rx_subsystem":1 [fmt:UYVY8_1X16/1920x1080 field:none]'
media-ctl -V '"80010000.v_proc_ss":0 [fmt:UYVY8_1X16/1920x1080 field:none]'
media-ctl -V '"80010000.v_proc_ss":1 [fmt:UYVY8_1X16/1920x1080 field:none]'
```
然后使用下面的命令在显示器上显示1920x1080的摄像头图像：\
`gst-launch-1.0 -e v4l2src device=/dev/video0 ! video/x-raw,format=YUY2,width=1920,height=1080 ! kmssink bus-id=fd4a0000.zynqmp-display fullscreen-overlay=1`
#### 6.3使用系统内置的脚本测试MIPI
连接显示器到DP口，连接MIPI摄像头到MIPI口，运行 *~/shells_for_testing_peripheral_devices/* 中的 *mipi_test.sh* 脚本(*ps：按**ctrl+c**组合键退出该脚本。*)：\
\
显示器中显示摄像头图像：\


---
### ⑦LEDS、KEYS
#### 7.1开发板上的LEDs和KEYs
开发板上有三组LED和KEY。第一组是POWER指示灯和RESET按钮，第二组是PS端的LED和KEY，第三组是PL端的LED和KEY。上电后默认POWER和PS_LED点亮：\

#### 7.2在Linux中使用LEDs和KEYs
使用LEDs和KEYs实际上就是配置和使用GPIO，在Linux中只需要知道GPIO号就可以使用对应的IO口。PS_LED的GPIO号为373，PS_KEY的GPIO号为359，PL_LED的GPIO号为509，PL_KEY的GPIO号为510。\
LED对应的IO需要配置成输出，以PS_LED为例，使用GPIO输出的步骤如下：
```
#导出对应的端口
echo 373 >> /sys/class/gpio/export
#设置这个端口为输出
echo out >> /sys/class/gpio/gpio373/direction
#使这个端口输出高电平，点亮LED
echo 1 >> /sys/class/gpio/gpio373/value
#使这个端口输出低电平，熄灭LED
echo 0 >> /sys/class/gpio/gpio373/value
```
KEY对应的IO需要配置成输出，以PL_KEY为例，使用GPIO输入的步骤如下：
```
#导出对应的端口
echo 510 >> /sys/class/gpio/export
#设置这个端口为输入
echo in >> /sys/class/gpio/gpio510/direction
#读取这个IO当前的电平状态
cat /sys/class/gpio/gpio510/value
```

#### 7.3使用系统内置的脚本测试LEDs和KEYs
运行 *~/shells_for_testing_peripheral_devices/* 中的 *leds_keys_test.sh* 脚本(*ps：按**ctrl+c**组合键退出该脚本。*)。然后可以用PS_KEY控制PS_LED点亮和熄灭，PL_KEY控制PS_LED点亮和熄灭：\


---
### ⑧M.2
#### 8.1什么是M.2
M.2是一种高速、低功耗的接口，用于连接外部设备，如固态硬盘、NVMe设备等等。\
M.2接口由PCI Express（PCIe）和SATA（串行ATA）两种协议组成，可用于数据传输、存储和通信。PCIe协议提供了更快的传输速度和更多的带宽，而SATA协议则更适合于低功耗和高容量的存储设备。
#### 8.2在系统中使用M.2接口
以SSD设备为例，在开发板的M.2接口上接上SSD(请不要带电操作)：\
\
然后启动开发板，登录Linux，如果能找到 */dev/nvme0n1* 说明SSD已经成功被识别到了。\
如果这个SSD已经被分过区了，那么还能找到 */dev/nvme0n1p1*, */dev/nvme0n1p2* 等分区对应的设备操作文件。\
如果SSD没有分区或者分区的文件系统格式Linux系统不支持，可以使用**fdisk**工具来分配分区，使用**mkfs**命令制作文件系统以及使用mount命令挂载。\
例如下面的命令将会删除 */dev/nvme0n1* 的第一个分区并新建一个分区，再把这个分格式化成ext4并挂载到 */run/media/nvme0n1p1* ：
```
#解挂分区
umount /dev/nvme0n1p1
#删除/dev/nvme0n1的一个分区并新建一个分区
echo "d

n
p
1

w
" | fdisk /dev/nvme0n1
#把/dev/nvme0n1p1分区格式化成ext4格式
echo "y

" | mkfs.ext4 /dev/nvme0n1p1
#挂载/dev/nvme0n1p1到/run/media/nvme0n1p1
mount /dev/nvme0n1p1 /run/media/nvme0n1p1
```
挂载之后，就可以在挂载的路径中操作文件了，而这些文件最终都会被保存在SSD中。
#### 8.3使用系统内置的脚本测试M.2 SSD
运行 *~/shells_for_testing_peripheral_devices/* 中的 *m.2_ssd_test.sh* 脚本：\
\
根据你的SSD的使用情况会用不同打印信息，但只要M.2接口和SSD是完好的最终肯定会输出\"*ssd read write OK* \"。

---
### ⑨PS_ETH
#### 9.1什么是ETH
在Linux操作系统中，\"ETH\" 通常指的是网络接口设备，它是用于在计算机与网络之间进行通信的硬件设备。在Linux中，可以使用 *ifconfig* 命令来管理和配置网络接口设备。可以通过ETH接口把开发板和其他网络设备连接在同一网络中，以便进行数据传输。\
在以太网协议中，每个设备都被分配一个唯一的MAC地址，以便在网络中进行识别和通信。当计算机通过网络接口设备发送数据时，它们将被封装在以太网帧中，并使用MAC地址进行路由和传输。\
开发板上的PS_ETH是PS端的ETH，PS_ETH则是PL端用IP实现的ETH，但是在系统中他们的使用方法都是一样的。
#### 9.2在Linux中使用ETH
连接PS_ETH和PL_ETH(比如通过路由器或交换机)到局域网：\
\
然后开发板上电，登陆系统，使用 *ifconfig* 可以查看当前ETH的状态：\
\
如果你的路由器或交换机支持DHCP，eth0和eth1都会自动连接并分配到ip。\
如果没有被分配ip则需要用下面的命令来手动分配，例如：\
`ifconfig eth0 192.168.8.67`\
*ifconfig* 命令还可以用来设置子网掩码；如果需要修改MAC地址则需要修改 */etc/network/interfaces* ；如果要设置网关则需要用到**route**命令；如果需要修改DNS则需要修改 */etc/resolv.conf* ，相关的配置就不详细讲了，一般来说只要通过网线连接到局域网，系统上电之后就可以直接使用eth0了。\
如果要使用eth1的话，还需要设置一下eth1的默认网关，网关的ip地址取决于你的局域网，**如果你的eth1和eth0接在同一个局域网的同一个网段则可以参考eth0的设置**，例如：
```
#先用route查看eth0的网关
route
#设置eth1的默认网关和eth0相同，假如上面route命令查看到eth0的默认网关为192.168.8.1
route add default gw 192.168.8.1 eth1
#再用route命令查看确认一下eth1的默认网关
route
```
\
可以使用**ping**命令来测试网络通断，通过 **-c** 参数设置ping的次数，通过 **-I** (大写的i)参数选择网口：\
`ping -c 1 -I eth1 www.baidu.com`\

#### 9.3使用系统内置的脚本设置并测试ETH
运行 *~/shells_for_testing_peripheral_devices/* 中的 *eth_test.sh* 脚本，这个脚本后可以带一个参数，即你想ping的地址，比如这里我ping了一下百度，如果不加参数则默认ping *www.google.com* ：\
\
最后会显示ping的结果和网口link的速度。

---
### ⑩PL_ETH
**见⑨PS_ETH**。

---
### ⑪USB x 4
#### 11.1什么是USB
USB是Universal Serial Bus的缩写，它是一种通用的数据传输标准，用于将计算机或其他设备与其他设备连接，包括打印机、键盘、鼠标、扫描仪、数字相机、移动设备和其他各种外部设备。\
随着技术的不断发展，USB的版本也在不断更新。USB 1.0是最早的版本，传输速度很慢，但是随着USB 2.0的推出，传输速度得到了显著提高。USB 3.0和USB 3.1是更快的版本，提供更高的传输速度和更多的功率。同时，USB还可以支持不同的数据传输协议，包括HID（人体接口设备）、音频、视频和存储设备等。\
我们的开发板上有四个USB3.0接口。
#### 11.2在Linux系统上使用USB
实际上常用USB设备都可以直接在这个系统上使用。比如鼠标键盘，都可以直接配合桌面来使用。使用U盘这些存储工具的话则需要注意分区和文件系统格式，可以参考**⑧M.2**中SSD的分区和格式化方法。U盘接入到系统之后，设备操作文件一般是 */dev/sda1* 、  */dev/sda2* 等等。
#### 11.3使用系统内置的脚本测试U盘
使用 *~/shells_for_testing_peripheral_devices/* 中的 *usb_drive_test.sh* 脚本( *ps：这个系统是不支持NTFS文件系统的，所以NTFS分区的U盘无法直接使用* )：\


---
### ⑫EMMC
#### 12.1什么是EMMC
eMMC（Embedded MultiMediaCard）是一种被嵌入式设备广泛采用的存储器件，它将闪存芯片、控制器、主机接口和闪存管理软件集成在一个小型封装中。eMMC的体积小、功耗低、性价比高，是嵌入式设备存储方案中的一种常见选择。\
eMMC主要应用于移动设备（例如智能手机、平板电脑、数字相机等）以及汽车、工业控制等领域的嵌入式设备中。它提供了一种高速、可靠的存储解决方案，支持快速启动和数据读写，可以存储操作系统、应用程序、媒体文件等数据。\
在我们的开发板上集成了一个8G的EMMC。
#### 12.2在Linux系统上使用EMMC
EMMC在Linux系统中的操作文件是 */dev/mmcblk0* ，使用方法和**⑧M.2**中SSD的使用方法类似：设置分区并格式化分区最后挂载分区。例如：
```
#解挂分区
umount /dev/mmcblk0p1
#删除/dev/mmcblk0的一个分区并新建一个分区
echo "d

n
p
1

w
" | fdisk /dev/mmcblk0
#把/dev/mmcblk0p1分区格式化成ext4格式
echo "y

" | mkfs.ext4 /dev/mmcblk0p1
#挂载/dev/mmcblk0p1到/media/sd-mmcblk0p1
mount /dev/mmcblk0p1 /media/sd-mmcblk0p1
```
挂载之后，就可以在挂载的路径中操作文件了，而这些文件最终都会被保存在EMMC中。
#### 12.3使用系统内置的脚本测试EMMC
运行 *~/shells_for_testing_peripheral_devices/* 中的 *emmc_test.sh* 脚本：\


---
### ⑬EEPROM
#### 13.1什么是EEPROM
EEPROM是一种非易失性存储器（NVM），它是电可擦可编程只读存储器（EPROM）的改进版本。EEPROM可以通过电子信号进行擦除和编程。\
EEPROM通常用于存储小量的数据，例如芯片上的配置信息、产品序列号、加密密钥等。在一些电子设备中，EEPROM还可以用来存储用户设置和个人资料等数据。\
与闪存相比，EEPROM具有更快的读取速度和更高的耐用性，但容量较小。与DRAM相比，EEPROM具有更长的数据保持时间，但写入速度较慢。
#### 13.2在Linux系统上使用EEPROM
eeprom在系统中的操作文件是 */sys/bus/i2c/devices/1-0050/eeprom* 。\
使用命令：\
`echo -e "test e2prom\n" > /sys/bus/i2c/devices/1-0050/eeprom`\
可以往eeprom中写入引号中的数据。\
使用命令：\
`cat /sys/bus/i2c/devices/1-0050/eeprom`\
可以查看eeprom中的内容。\

#### 13.3使用系统内置的脚本测试EEPROM
运行 *~/shells_for_testing_peripheral_devices/* 中的 *eeprom_test.sh* 脚本：\


---
### ⑭QSPI FLASH
#### 14.1什么是QSPI FLASH
Flash是一种高速闪存存储器，常用于嵌入式系统和其他应用中，用于存储程序代码、配置数据和其他信息。\
QSPI Flash是一种基于SPI接口的闪存芯片，它通过四个并行数据线（quad interface）进行通信，与传统的SPI Flash相比，可以实现更快的数据传输速度，通常达到几十MHz的传输速度。QSPI Flash的容量通常在几兆字节到几十兆字节之间。\
QSPI Flash具有许多优点，包括快速读写速度、低功耗、可擦写性、易于集成和使用等。此外，它还可以通过软件进行编程和擦除，而无需任何外部设备或信号线。
#### 14.2在Linux系统上使用QSPI FLASH
在当前的Linux系统中QSPI FLASH被用于存储u-boot的环境变量，如果修改了u-boot的环境变量那么操作QSPI FLASH就需要小心了。\
QSPI FLASH在系统中的操作文件是 */dev/mtd0*。\
FLASH设备在写之前需要先擦，使用下面的命令可以擦除QSPI FLASH的第一个扇区：\
`flash_erase /dev/mtd0 0 1`\
*/dev/mtd0* 是块设备，可以用**dd**命令来读写文件到 */dev/mtd0*。\
用下面的命令写文件到 */dev/mtd0* ：
```
touch /home/root/.qspiflashwrite
echo "qspiflash test" > /home/root/.qspiflashwrite
dd of=/dev/mtd0 if=/home/root/.qspiflashwrite bs=4096 count=1
```
用下面的命令从 */dev/mtd0* 读取数据到文件：
```
touch /home/root/.qspiflashread
dd if=/dev/mtd0 of=/home/root/.qspiflashread  bs=4096 count=1
```
#### 14.3使用系统内置的脚本测试QSPI FLASH
运行 *~/shells_for_testing_peripheral_devices/* 中的 *qspi_flash_test.sh* 脚本：\


---
### ⑮RTC
#### 15.1什么是RTC
实时时钟(RTC)单元为整个系统和应用软件提供了一个精确的时间基准。
#### 15.2在Linux系统上使用RTC
在我们的Linux系统中，RTC的设备操作文件是 */dev/rtc0*。可以用**hwclock**命令来读写 */dev/rtc0*。例如：
```
#设置系统时间为"2023-03-01 10:30:00"
date --set="2023-03-01 10:30:00"
#把系统时间写入到/dev/rtc0
hwclock -f /dev/rtc0 -w
#用/dev/rtc0中的时间更新系统时间
hwclock -f /dev/rtc0 -r
```

#### 15.3使用系统内置的脚本测试RTC
运行 *~/shells_for_testing_peripheral_devices/* 中的 *rtc_test.sh* 脚本：\


---
### ⑯LM75
#### 16.1什么是LM75
LM75是一种数字温度传感器芯片，由德州仪器（Texas Instruments）公司生产。它可以测量环境温度，并通过I2C总线与其他设备进行通信。是一个性能稳定、精度高、可靠性好的数字温度传感器芯片。
#### 16.2在Linux系统上使用LM75
在Linux中直接读取 */sys/bus/i2c/devices/1-0048/hwmon/hwmon0/temp1_input* 就可以获取到LM75采集的温度值，**单位是m°C**：\
`cat /sys/bus/i2c/devices/1-0048/hwmon/hwmon0/temp1_input`\
\
这里读到的温度是31750m°C，也就是31.75°C。

---
---
- 访问[ALINX官方网站](https://www.alinx.com)以获取更多信息。

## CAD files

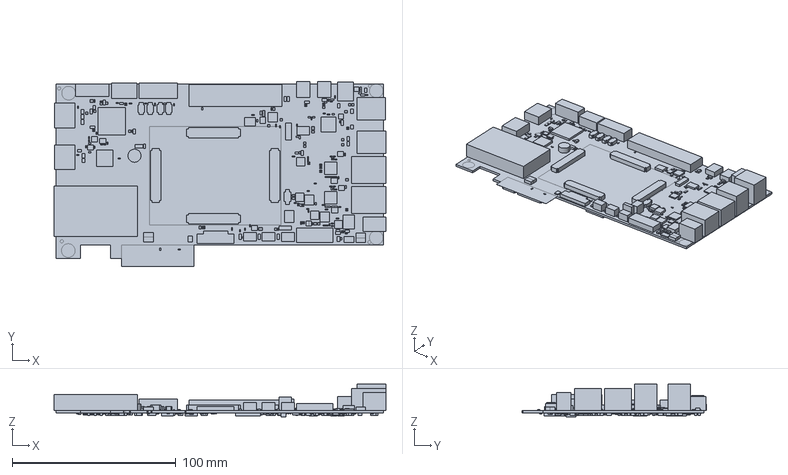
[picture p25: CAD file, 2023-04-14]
hardware/STEP_Models/AXU4EV-P_AXU5EV-P.stp
202.7 x 112.7 x 20.1 mm
BOARD_OUTLINE
ASP_134603_01
QFN-28 x 2
MICRO8
SOIC14
SOT23 x 4
SO8 x 4
QFN24_RTW
R1206
MICRO_SD
CN1-DCJACK
GE_RJ45 x 2
FUSE_1812
CC0805 x 9
SIP3-2_54
CON2_2_54P
MP1482-SOIC8 x 2
L5_2X5_2 x 2
SO16
SOT-23 x 5
HDMI_A_TYPE x 2
JTAG-10
HT3_81-4PL
HT3_81-6PL
LQFP-100
C0805 x 60
C0603 x 11
LED_0805 x 3
L0805 x 8
C0402 x 239
R0402 x 202
MDT420M02001_PCIE
SFPX2_CASE
BATT_CON
OSC6-3225
FPC100C047
USB3_AF_90_DUAL x 2
SON10 x 7
SOT23-6 x 3
SOD-123
SOT23-5 x 2
KEY_4X4X1_5 x 3
MINI_DP_LC
QFN76
L3_1X3_1
SOIC_8 x 3
R0805 x 2
SOT-23-6
MINI_USB_DIP x 2
LL0603 x 27
SMBJ6-0CA x 4
SX2-1205 x 4
GTL2002GM
QFN40
C1206
SOT23-3 x 3
SOT3 x 4
OSC3_2X2_5
8S1_SOIC8
PCIE_4LANE_EDGE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

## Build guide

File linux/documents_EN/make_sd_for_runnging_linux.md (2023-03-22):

[Back to Home](../)
## Start the linux on the development board from the SD card

---
### 1.Adjust the dial switch
Adjust the dial switch on the development board to the state of starting from the SD card, as shown below:\
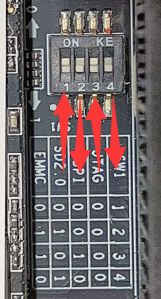
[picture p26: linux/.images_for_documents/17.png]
\
This position of the dial -dial switch is in the development board:\
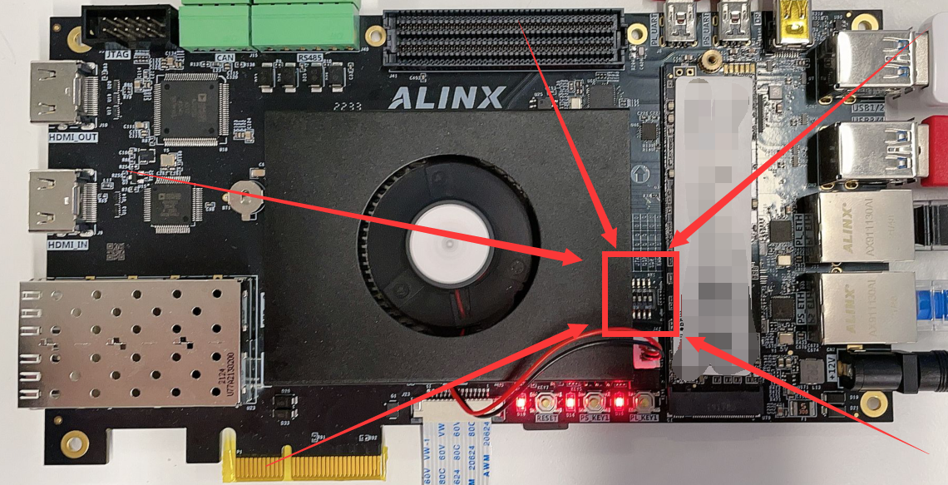
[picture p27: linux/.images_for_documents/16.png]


---
### 2.Set SD card partition
Next, you need to make the SD card for launching Linux. Connect the SD card (such as a card reader) to the Ubuntu system, and then open the DISKS tool in the Ubuntu system:\
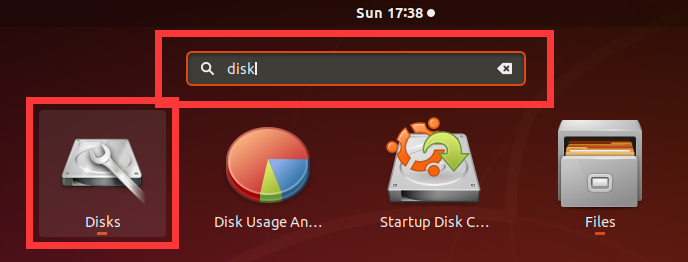
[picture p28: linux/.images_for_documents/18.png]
\
My SD card is the **31 GB Drive** here. Select it, you can see that there are three areas in the SD card:\
a. FAT type partition named **BOOT**\
b. Ext4 type partition named **ROOTFS**\
c. Free Space\
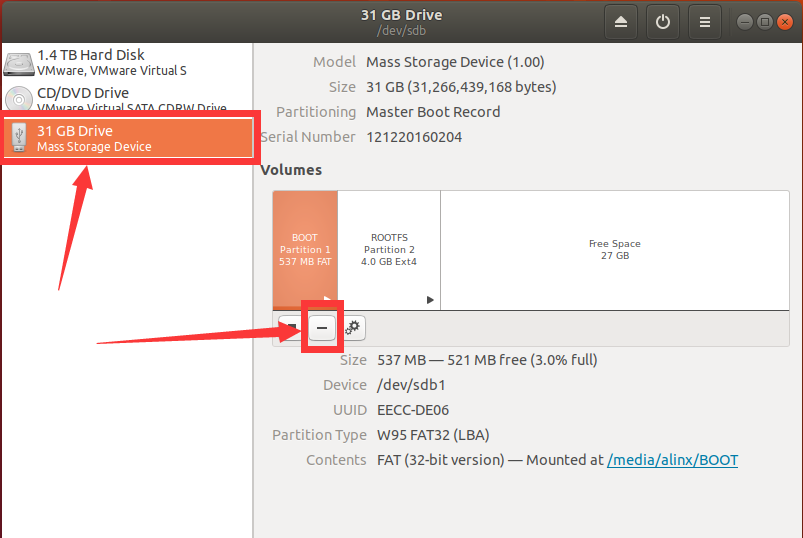
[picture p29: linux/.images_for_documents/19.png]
\
This is the state we need. If your SD card is in the same state (there is no strict requirement on the size of the partition), just skip step [2]. However, in order to demonstrate a complete process, I will restore the SD to the state without partition, select the corresponding partition, click the \" **-** \" icon to delete the current partition, and finally change to the state as shown below:\
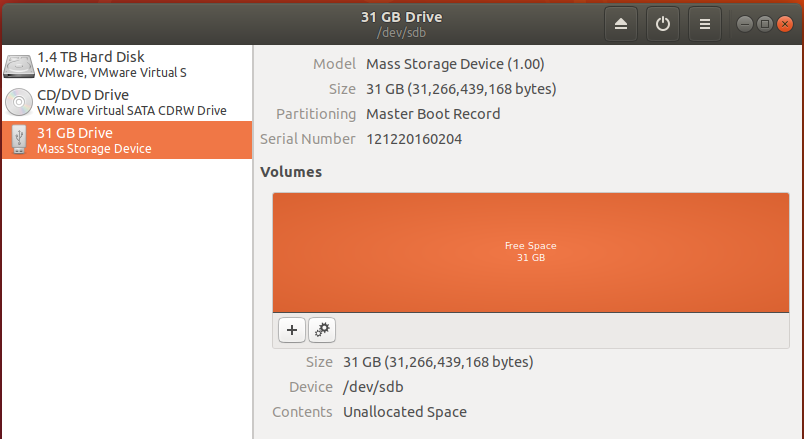
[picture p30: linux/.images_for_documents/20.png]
\
Click the \" **+** \" icon to create a new partition. The first partition needs to be in the format of **FAT**, with a size of 2G and a name of **BOOT**:\
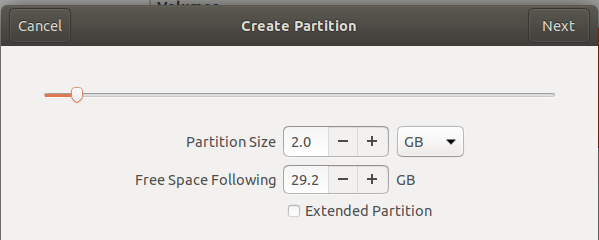
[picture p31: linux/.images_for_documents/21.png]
\
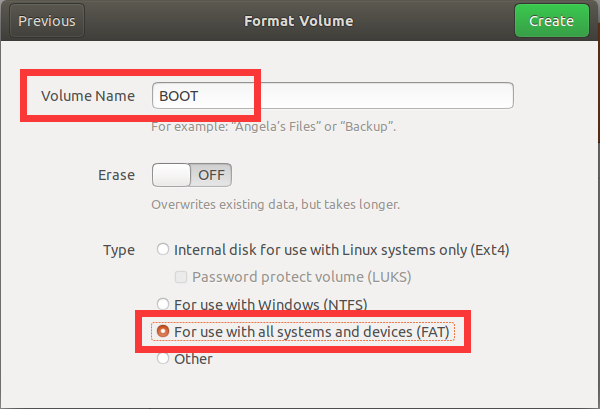
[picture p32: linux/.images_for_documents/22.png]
\
Click the **Create** button to complete the partition creation, and click \" **▶** \" button mount partition:\
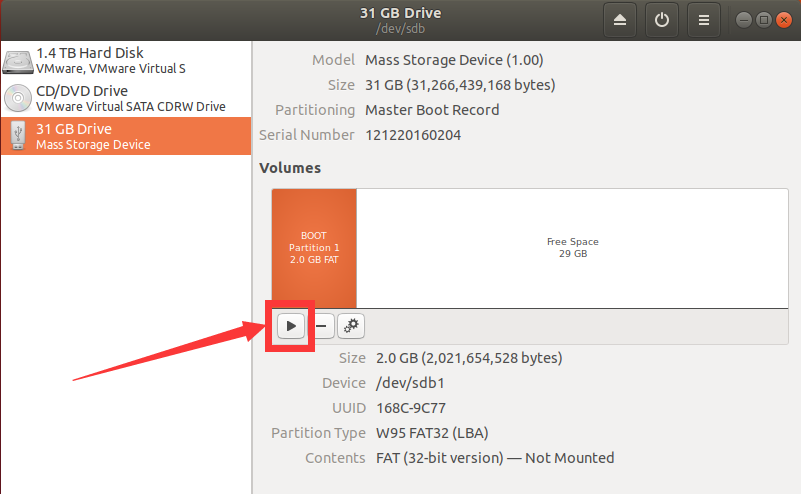
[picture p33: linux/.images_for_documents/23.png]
\
Click **Free Space** to create a second partition using similar steps. Select **Ext4** as the format. The size allocation is 20G (adjusted according to your actual needs and restrictions). The name is **ROOTFS**:\
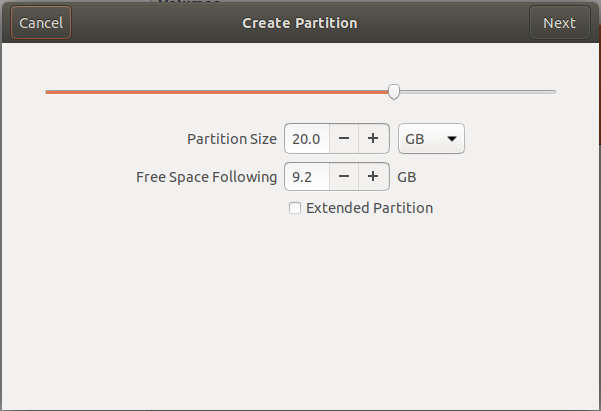
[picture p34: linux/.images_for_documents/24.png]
\
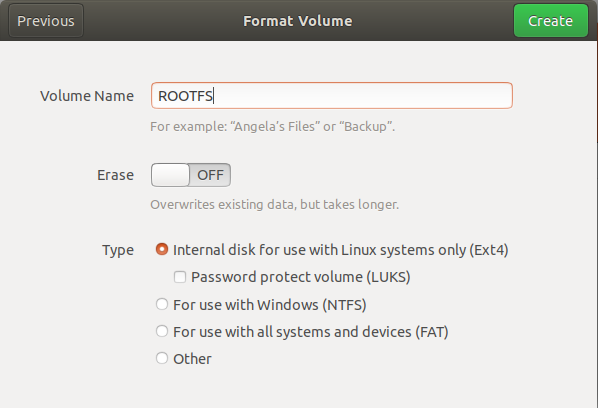
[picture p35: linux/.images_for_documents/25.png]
\
The final status is shown in the following figure. Note that you need to mount both partitions:\
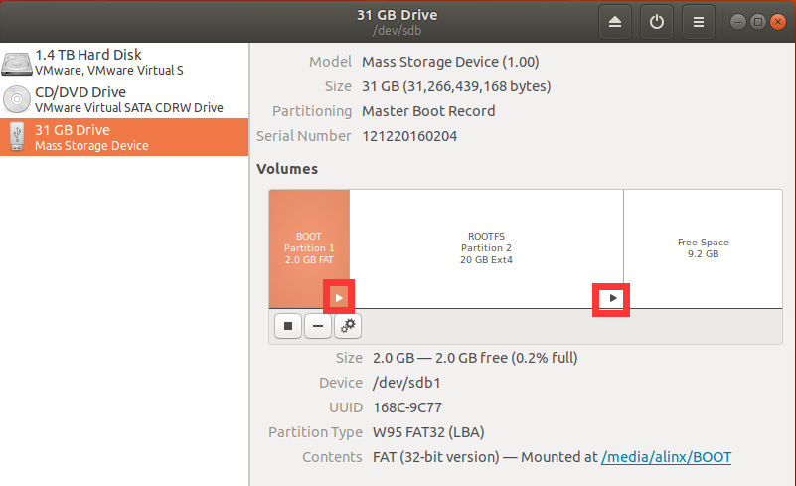
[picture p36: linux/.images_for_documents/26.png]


---
### 3.Populate SD card partitions
After the partition of the SD card is completed, copy the files needed to start the system to the corresponding partition.\
Ps: You can find *boot. scr*, *BOOT. bin*, *image. ub*, *rootfs. tar. gz*  in the release version. You can also compile the petalinux project to obtain these files.\
Copy the *boot.scr*, *BOOT.bin*, and *image.ub* files to the **BOOT** partition:\
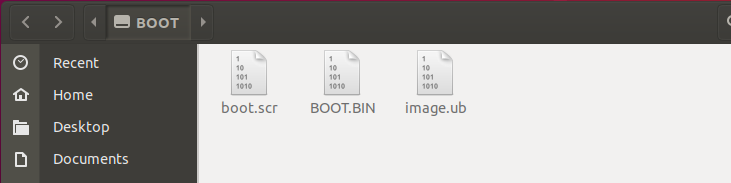
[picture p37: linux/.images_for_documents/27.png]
\
Extract *rootfs.tar.gz* to the **ROOTFS** partition with root privileges, open the terminal in the path of *rootfs.tar.gz*, and enter the following command:\
`sudo tar zxvf ./rootfs.tar.gz -C /media/alinx/ROOTFS/ && sync`\
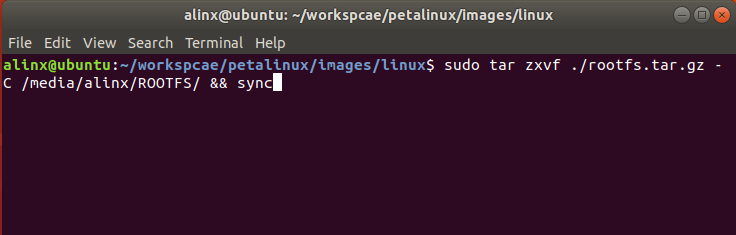
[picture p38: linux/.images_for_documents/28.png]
\
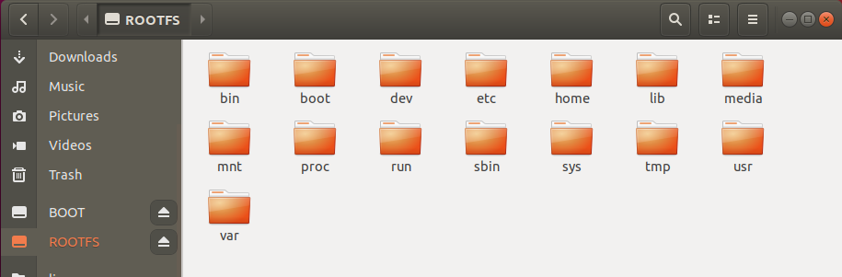
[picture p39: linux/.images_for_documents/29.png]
\
Then eject the SD card from Ubuntu.

---
### 4.Start Linux
Insert the SD card just made into the SD card slot of the development board:\
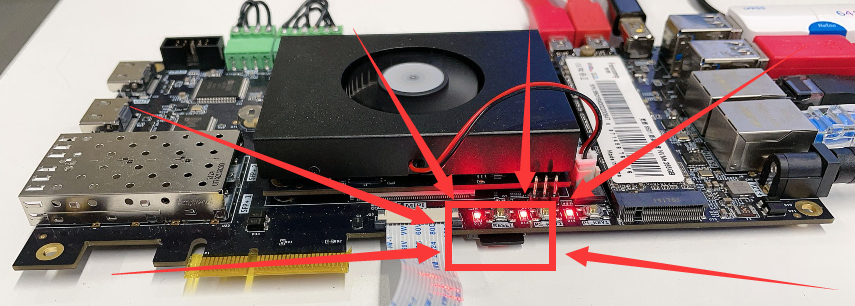
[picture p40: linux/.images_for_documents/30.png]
\
Connect PS_UART to PC (***The driver of CP210x needs to be installed on the PC*** ):\
\
Open the serial port tool, select the COM port we just connected, set the baud rate to 115200, close the flow control, and click the OK button:\
\
Connect 12V power supply:\
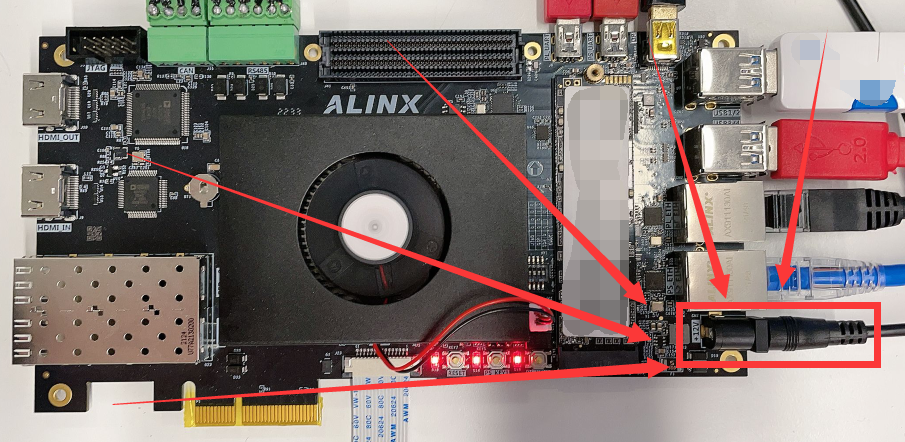
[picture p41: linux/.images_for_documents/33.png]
\
You can see the output information in the serial port tool:\
\
The system has been started successfully. Enter the user name **root** and password **root** to log in to the system.

---
---
- Visit [ALINX official website](https://www.alinx.com) for more information.

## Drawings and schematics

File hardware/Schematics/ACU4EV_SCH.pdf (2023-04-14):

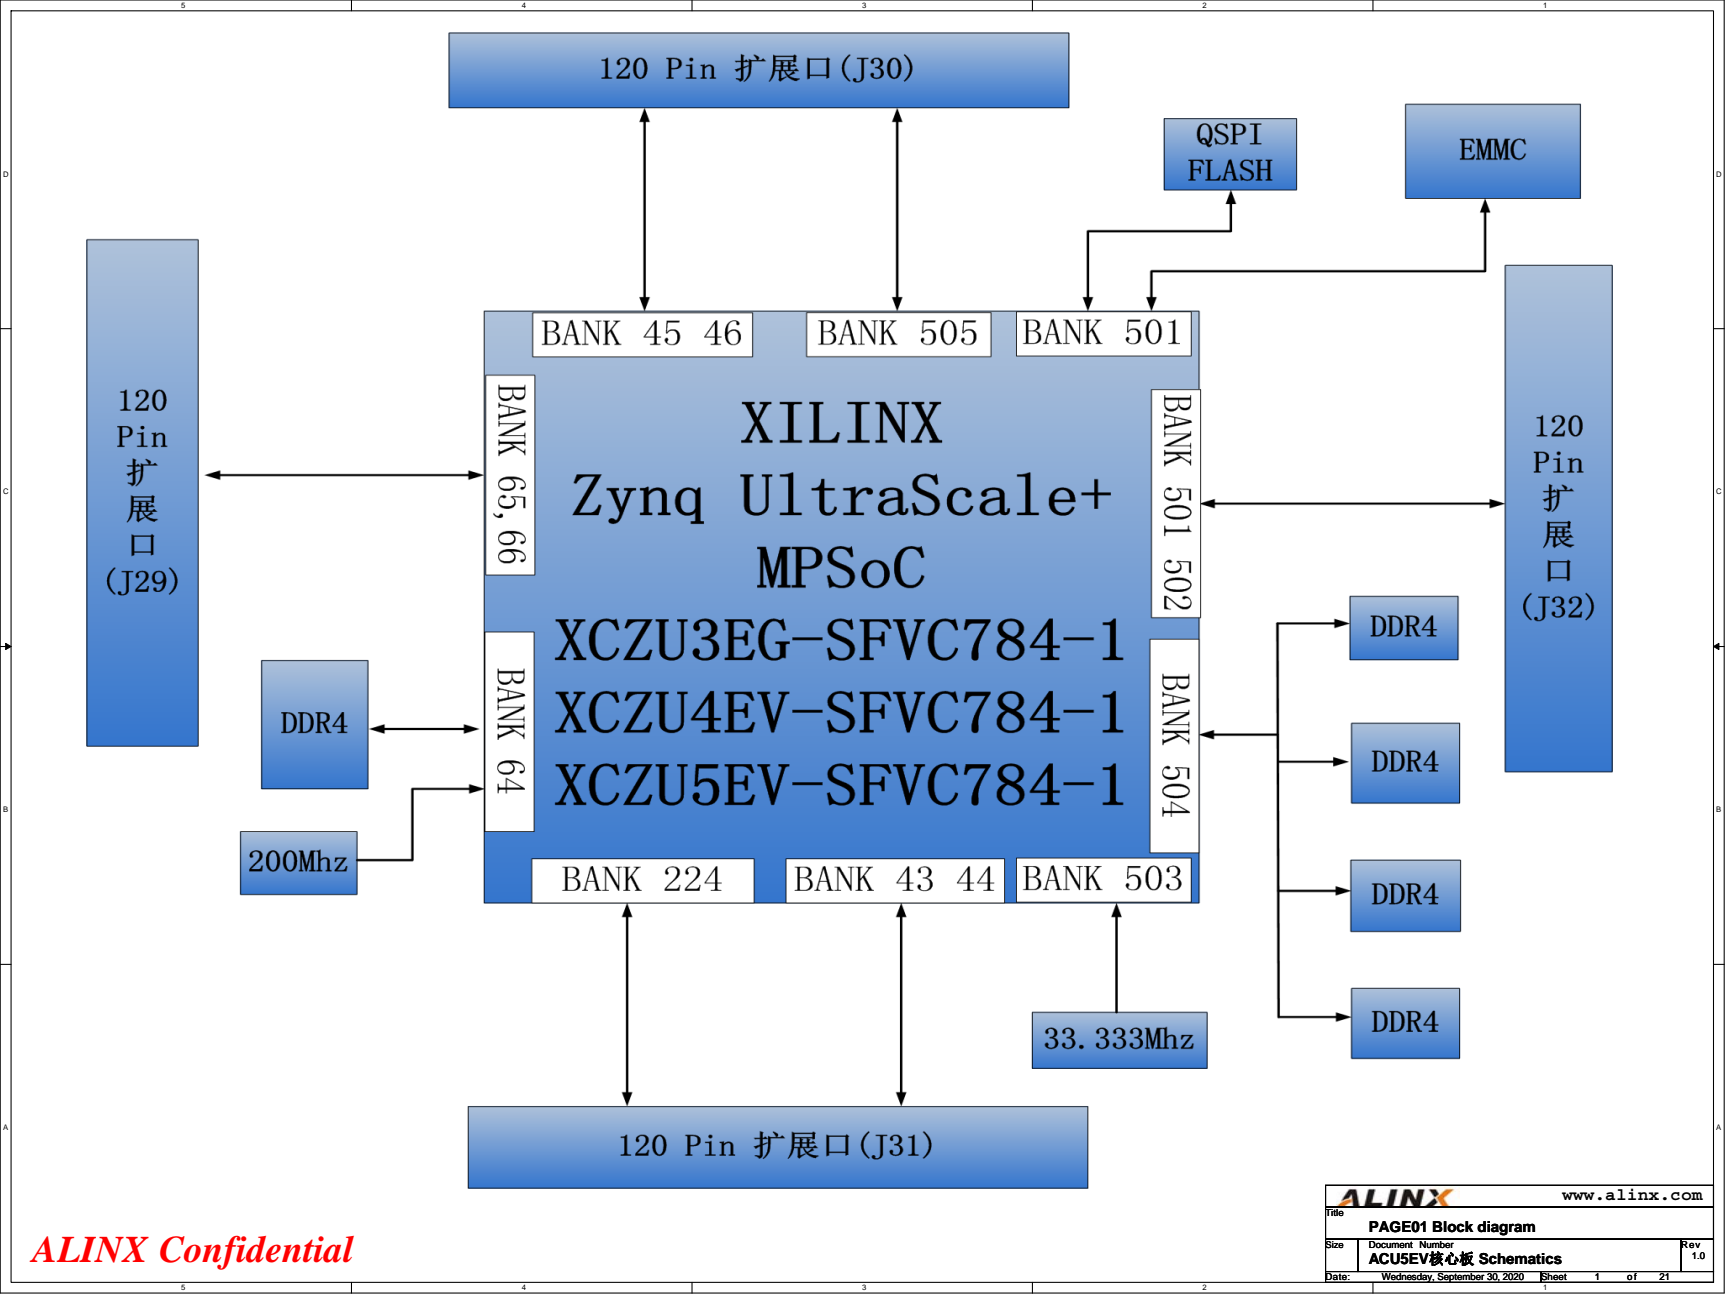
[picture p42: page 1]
ALINX Confidential; Title; PAGE01 Block diagram

www.alinx.com

Size | Document Number ACU5EV核心板 Schematics | Rev 1.0

Date: Wednesday, September 30, 2020 Wednesday, September 30, 2020 Wednesday, September 30, 2020 | Sheet 1 1 1 of 21 21 21

# MODE[3:0]

0000 | PS JTAG | PS JTAG Interface

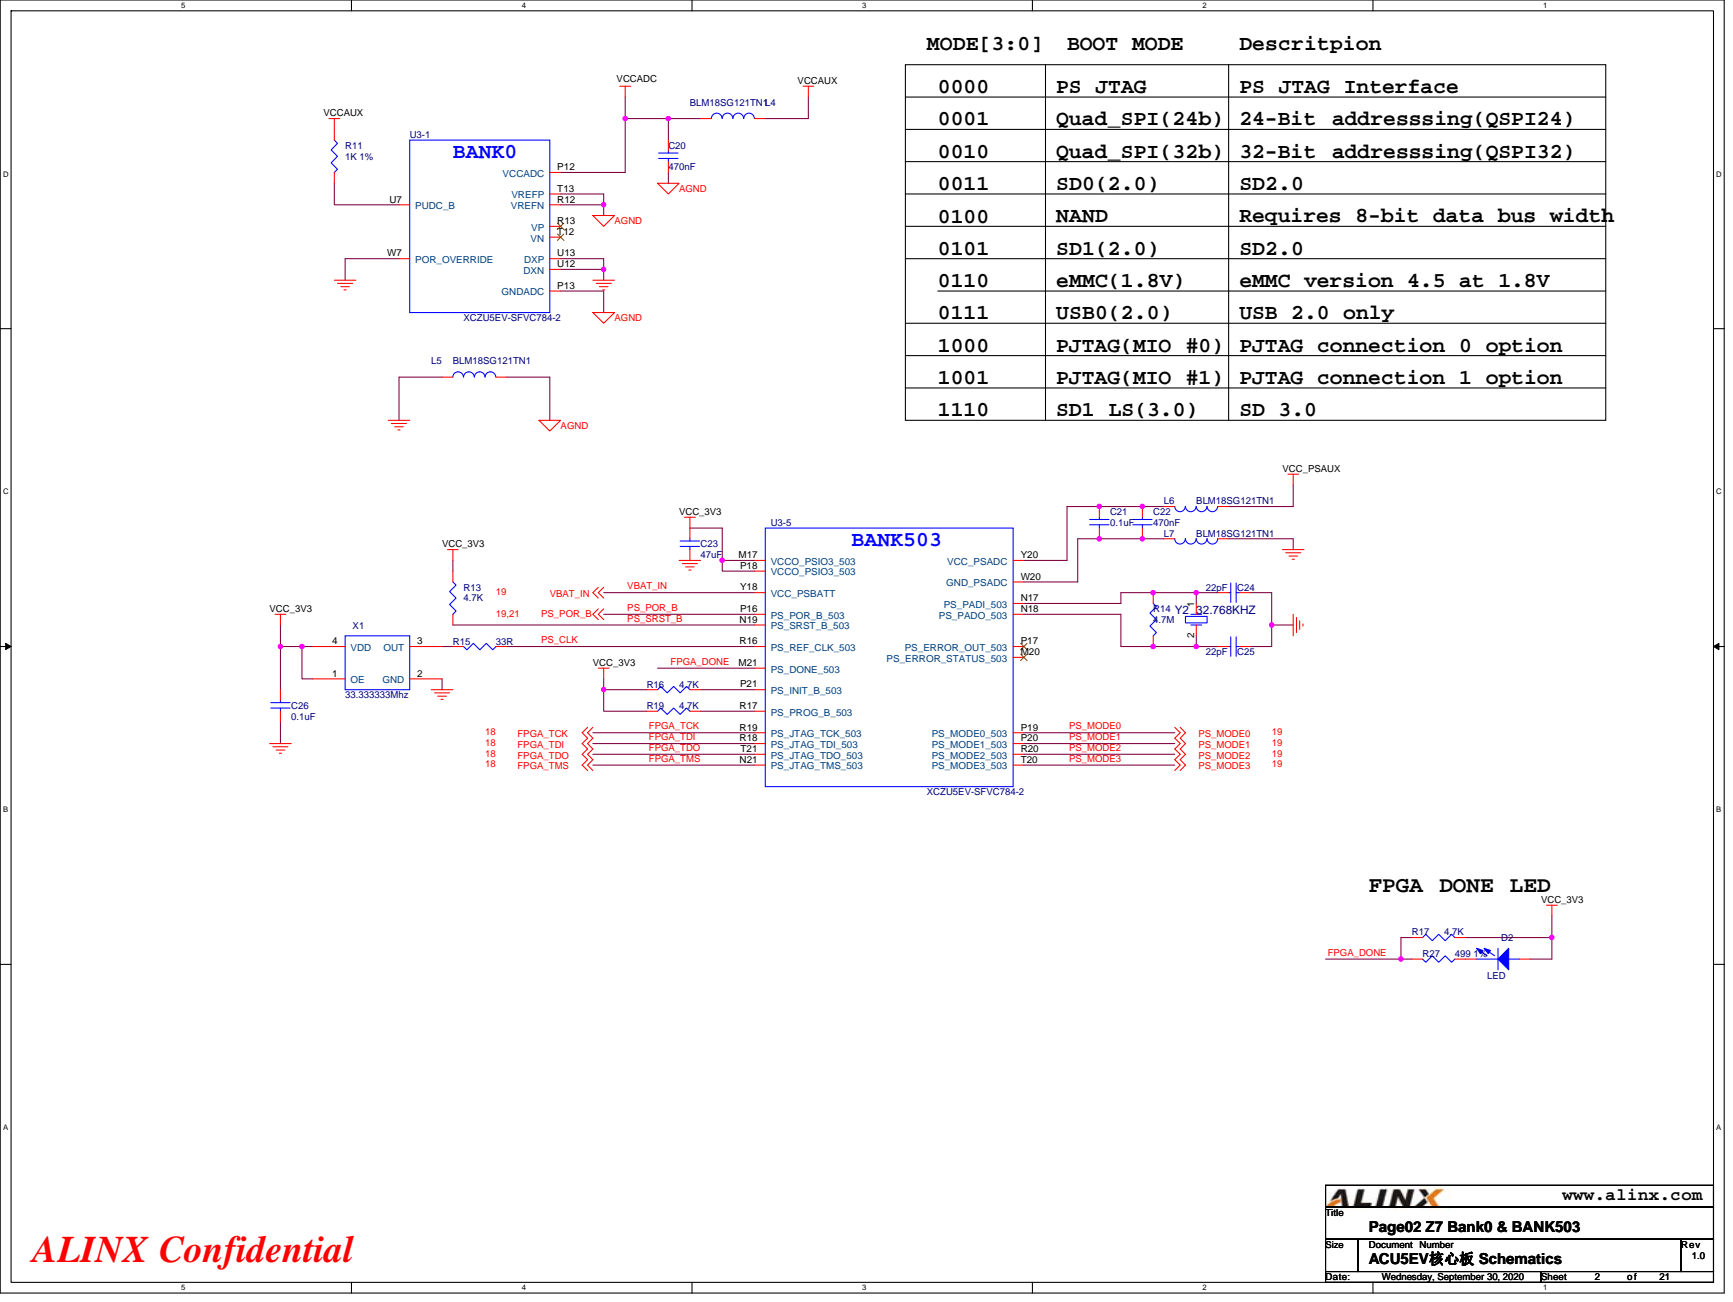
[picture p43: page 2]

0001 | Quad_SPI(24b) | 24-Bit addresssing(QSPI24)
0010 | Quad_SPI(32b) | 32-Bit addresssing(QSPI32)
0011 | SD0(2.0) | SD2.0
0100 | NAND | Requires 8-bit data bus width
0101 | SD1(2.0) | SD2.0
0110 0111 | eMMC(1.8V) USB0(2.0) | eMMC version 4.5 at 1.8V USB 2.0 only

1000 | PJTAG(MIO #0) | PJTAG connection 0 option
1001 | PJTAG(MIO #1) | PJTAG connection 1 option
1110 | SD1 LS(3.0) | SD 3.0

## VCC1V8

0.1uF | BANK500

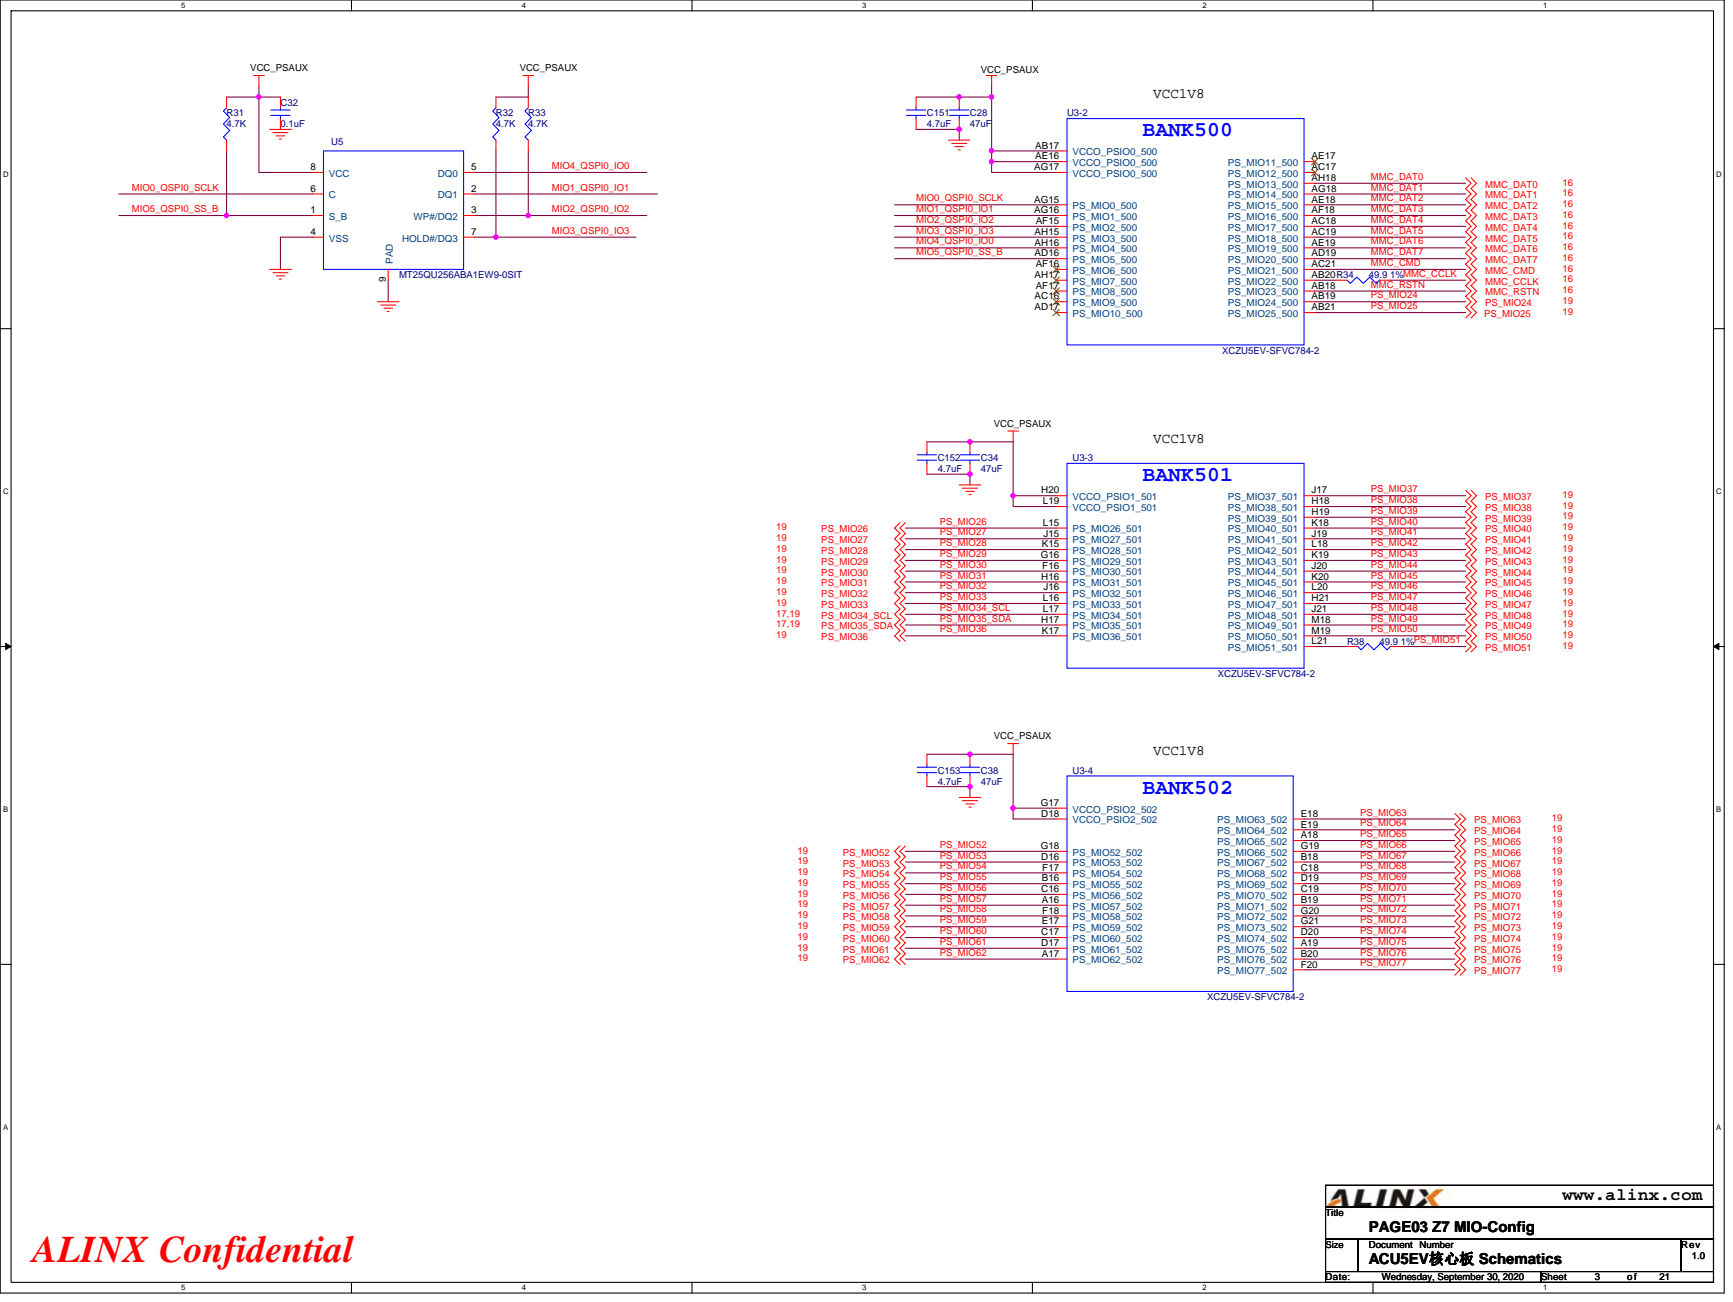
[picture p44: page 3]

# BANK43

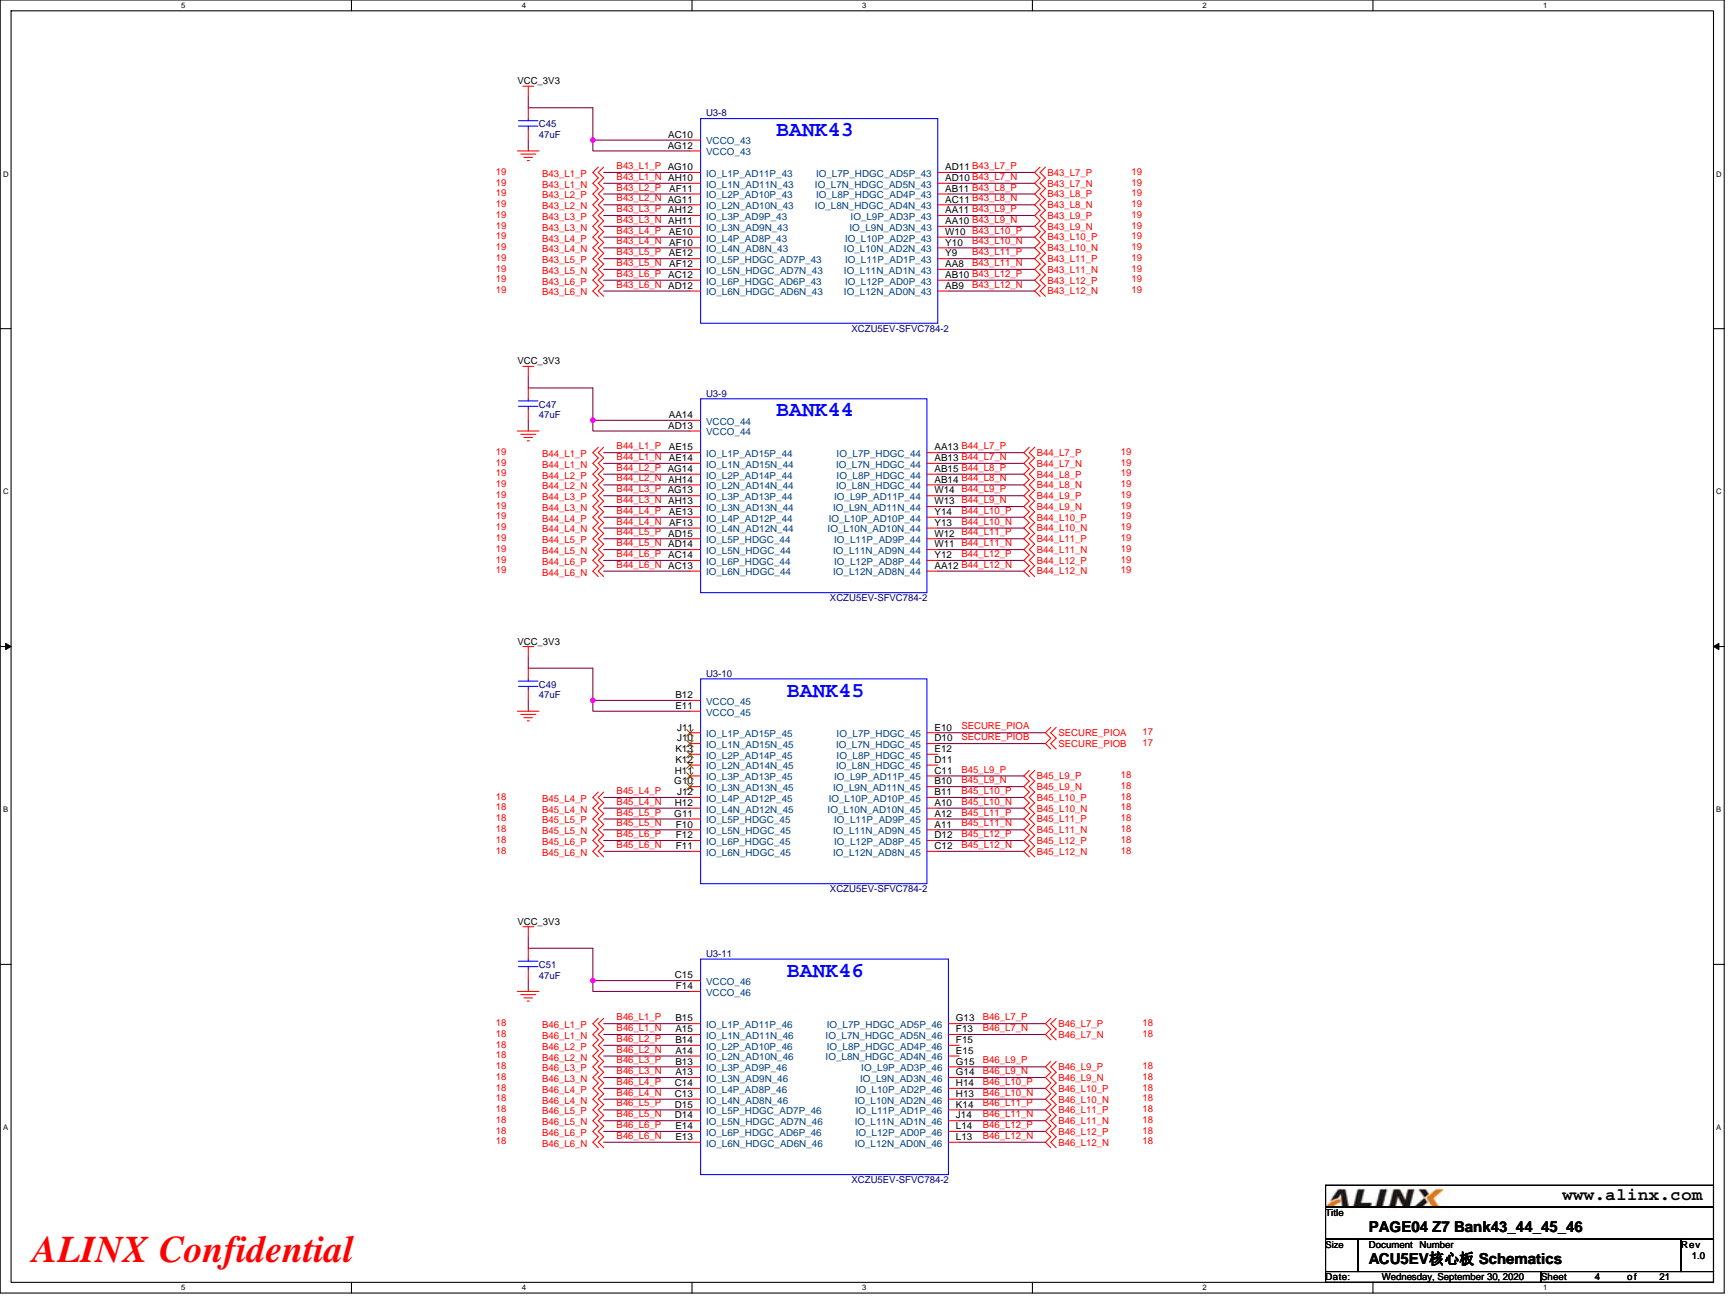
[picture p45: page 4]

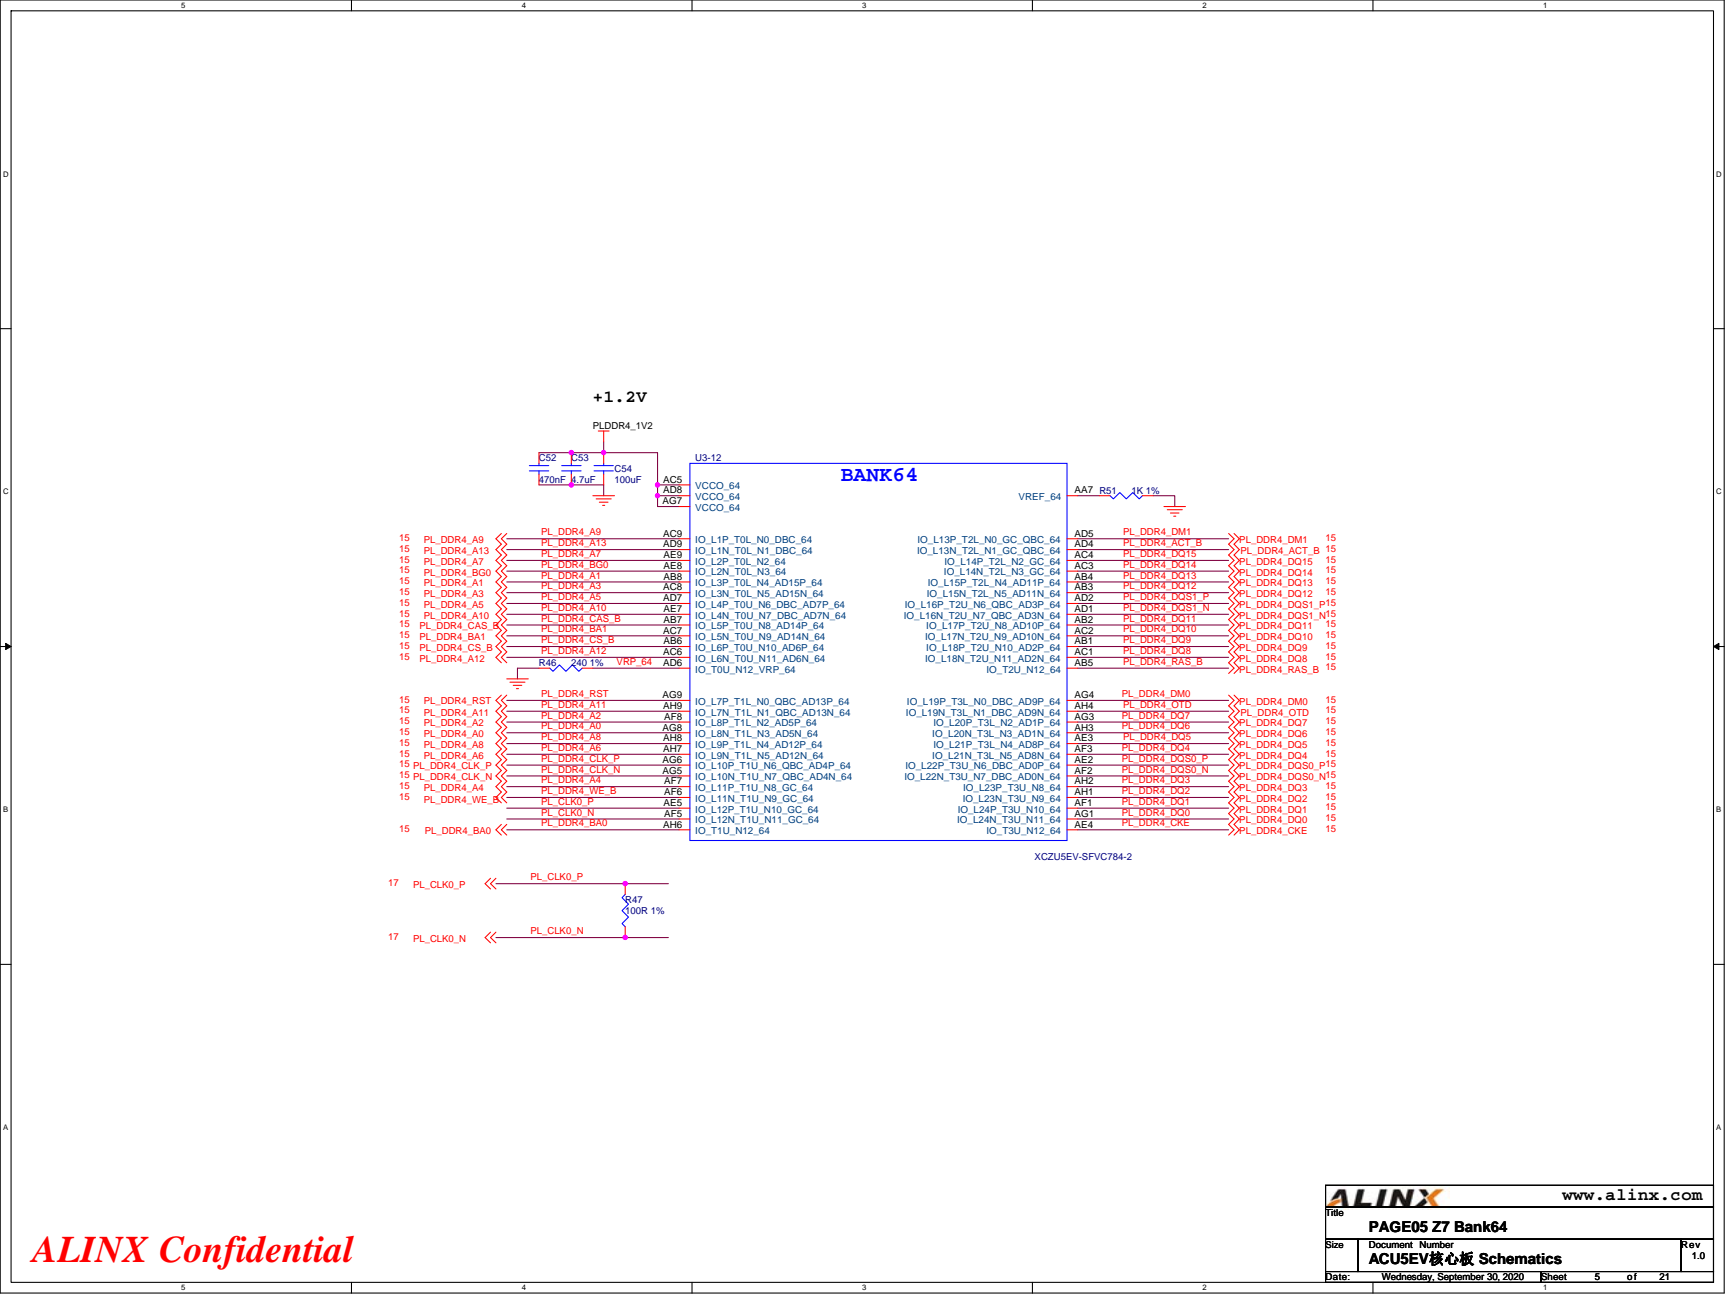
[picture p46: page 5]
VRP_64; PL_DDR4_A0; PL_DDR4_CLK_P PL_DDR4_CLK_N; PL_CLK0_P PL_CLK0_N; PL_CLK0_N; PL_CLK0_P; PL_DDR4_DM1; PL_DDR4_DQ0; PL_DDR4_DQ7 PL_DDR4_DQ6; PL_DDR4_DQS0_P; PL_DDR4_DQ1; PL_DDR4_DQS0_N; PL_DDR4_DQ2; PL_DDR4_DQ5 PL_DDR4_DQ4; PL_DDR4_DQ3; PL_DDR4_DM0; PL_DDR4_DQ15 PL_DDR4_DQ14 PL_DDR4_DQ13 PL_DDR4_DQ12; PL_DDR4_DQ11 PL_DDR4_DQ10 PL_DDR4_DQ9 PL_DDR4_DQ8; PL_DDR4_DQS1_P PL_DDR4_DQS1_N; PL_DDR4_OTD; PL_DDR4_A6; PL_DDR4_BA1; PL_DDR4_A9; PL_DDR4_A5; PL_DDR4_CS_B; PL_DDR4_BA0; PL_DDR4_A13 PL_DDR4_A7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

www.alinx.com

# BANK65

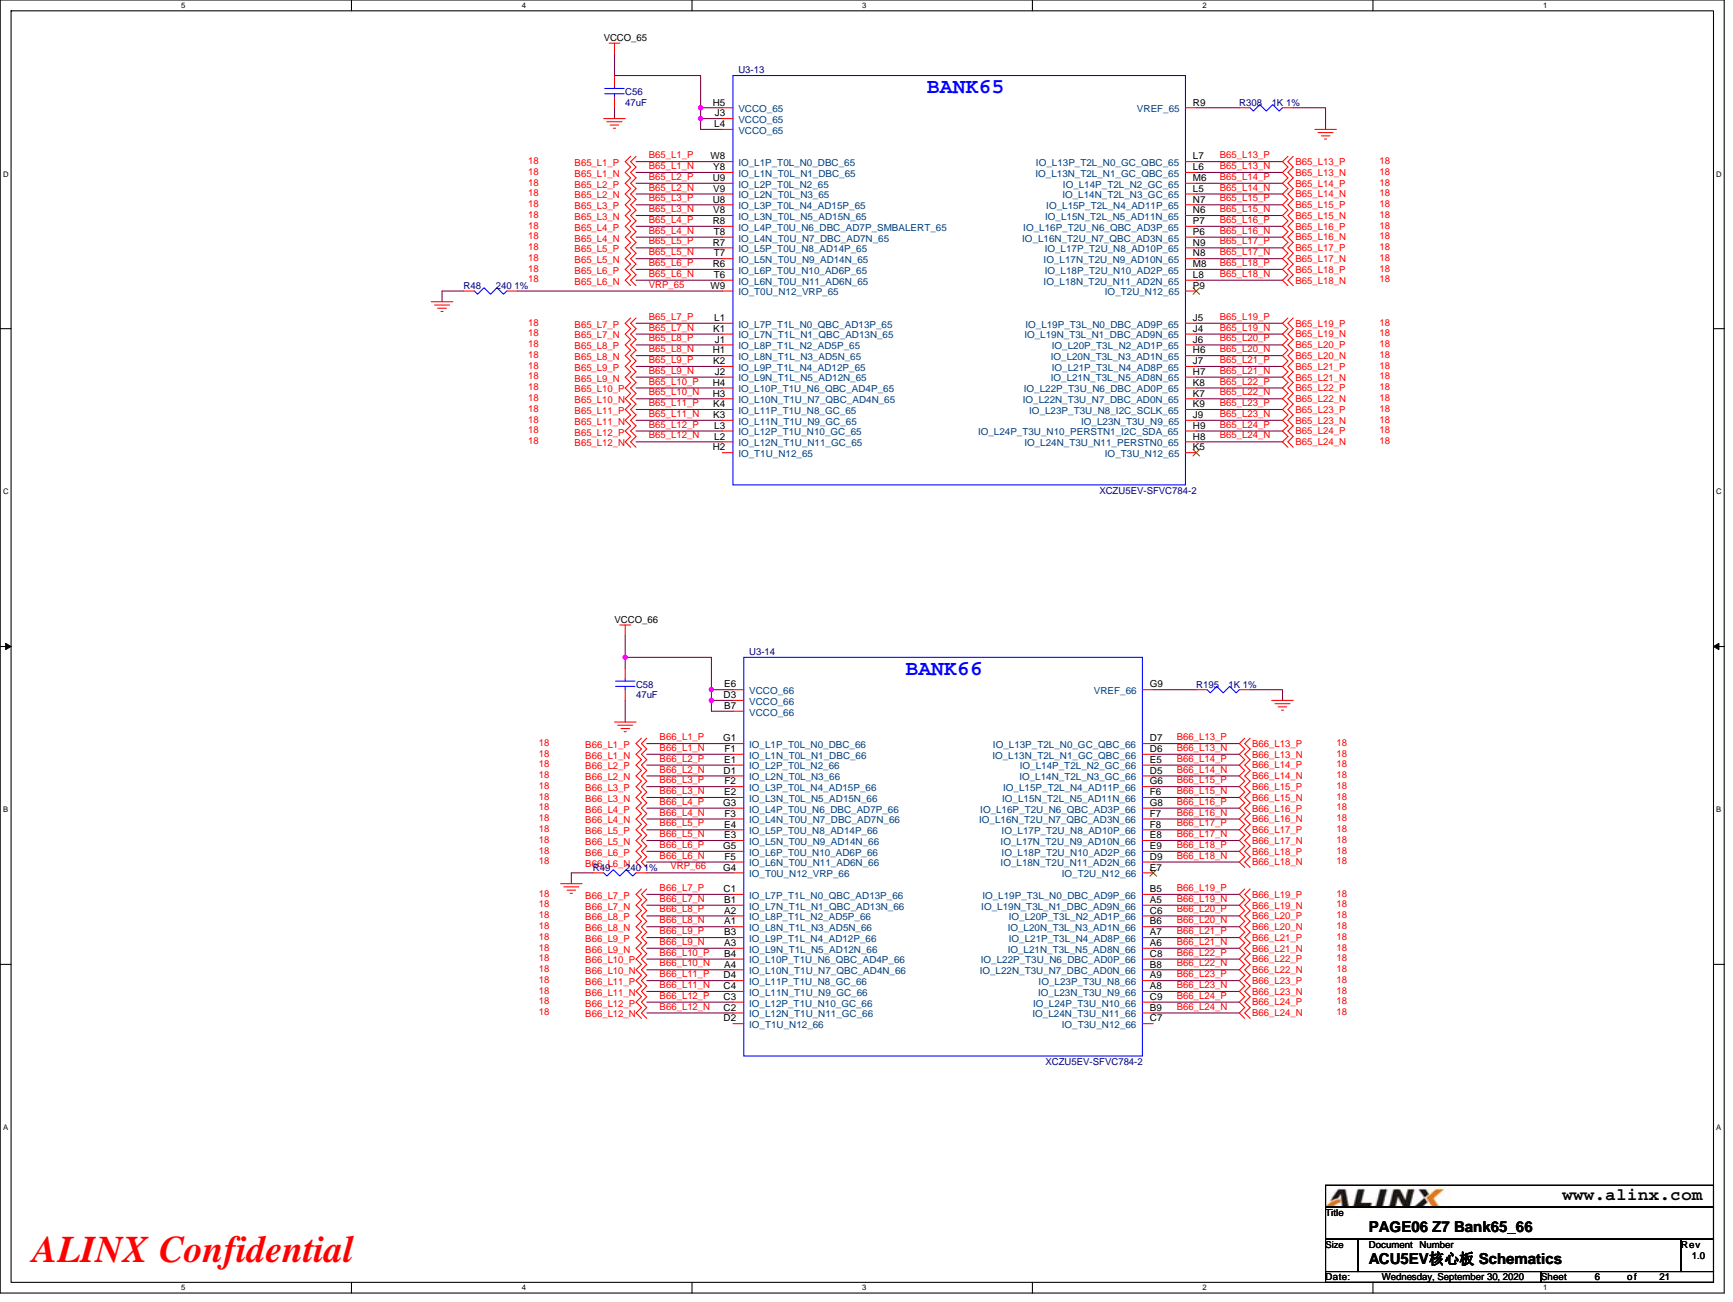
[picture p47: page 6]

# BANK505 PS MGT

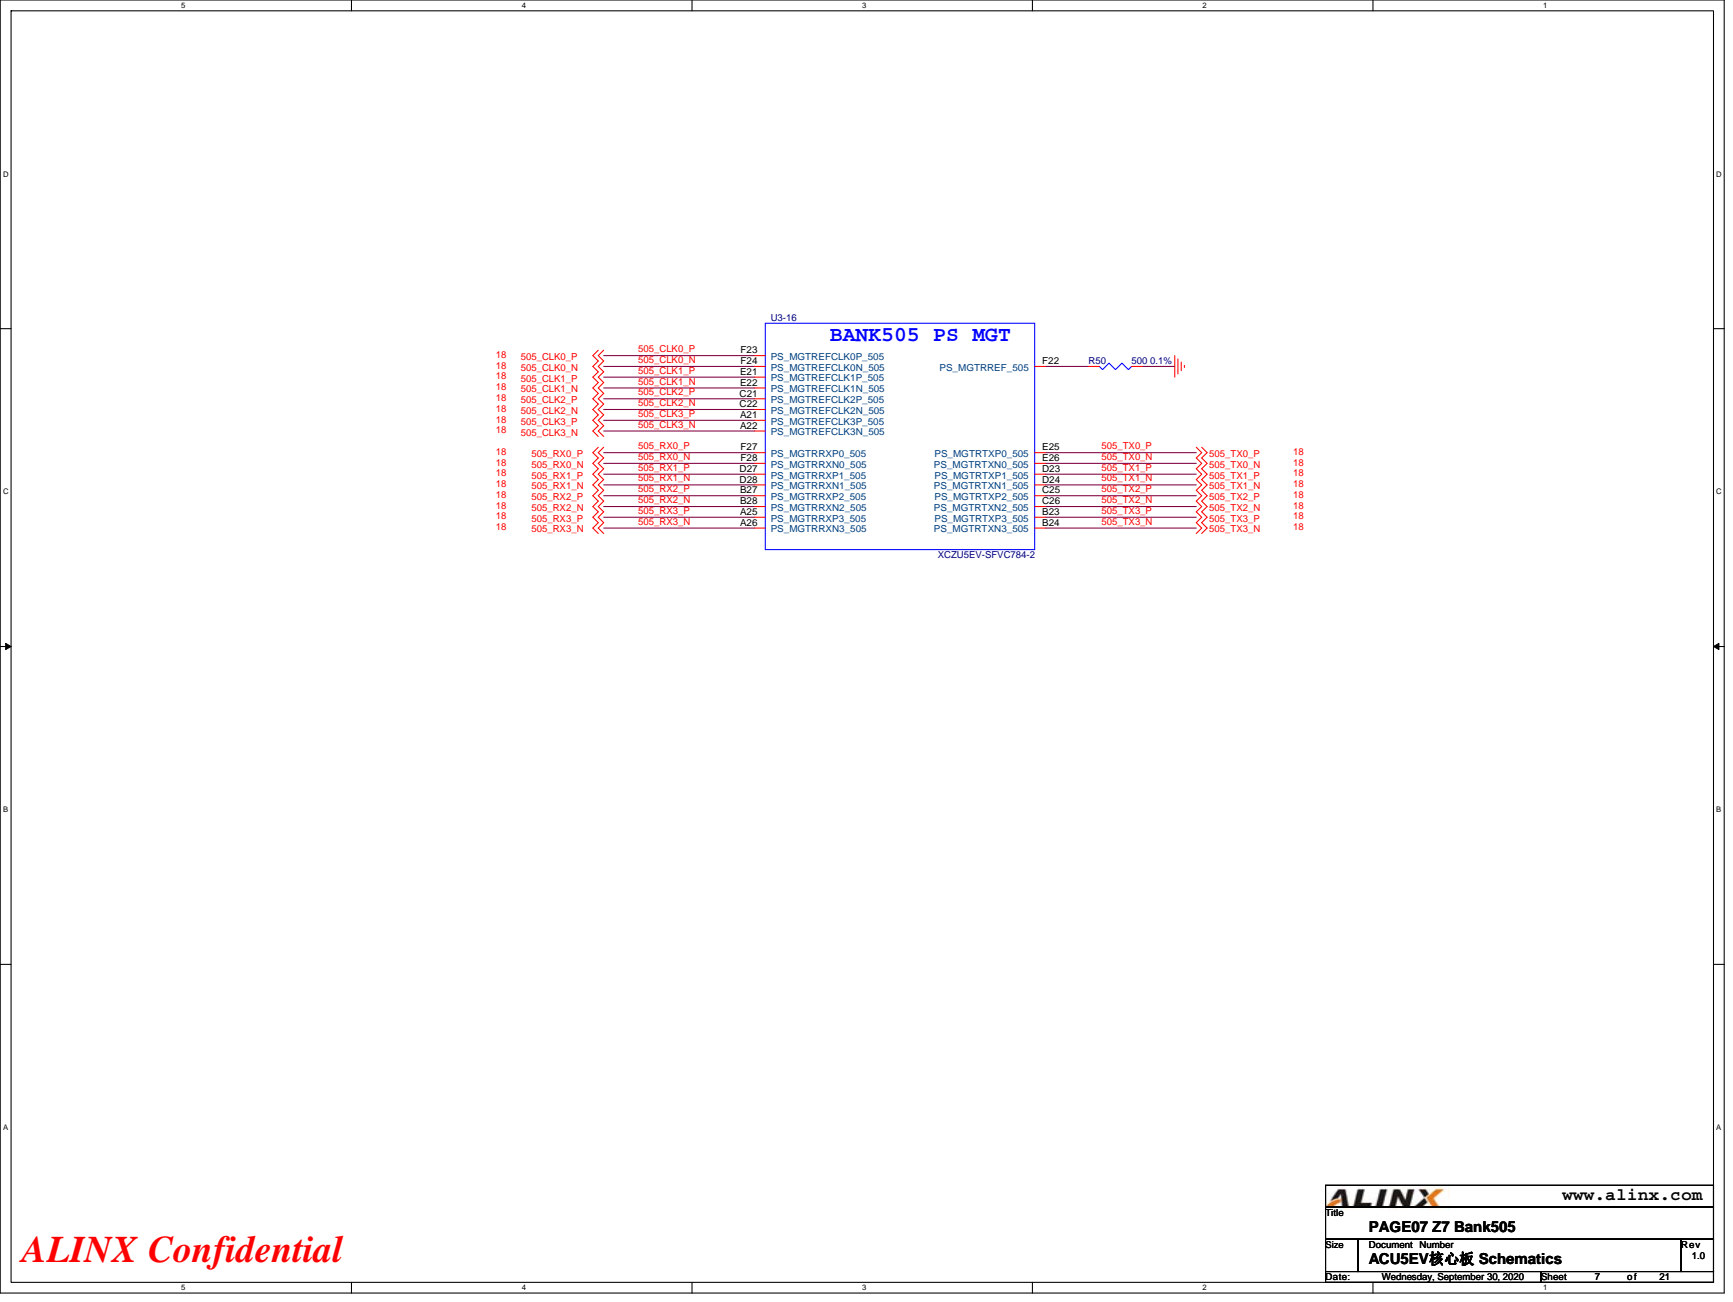
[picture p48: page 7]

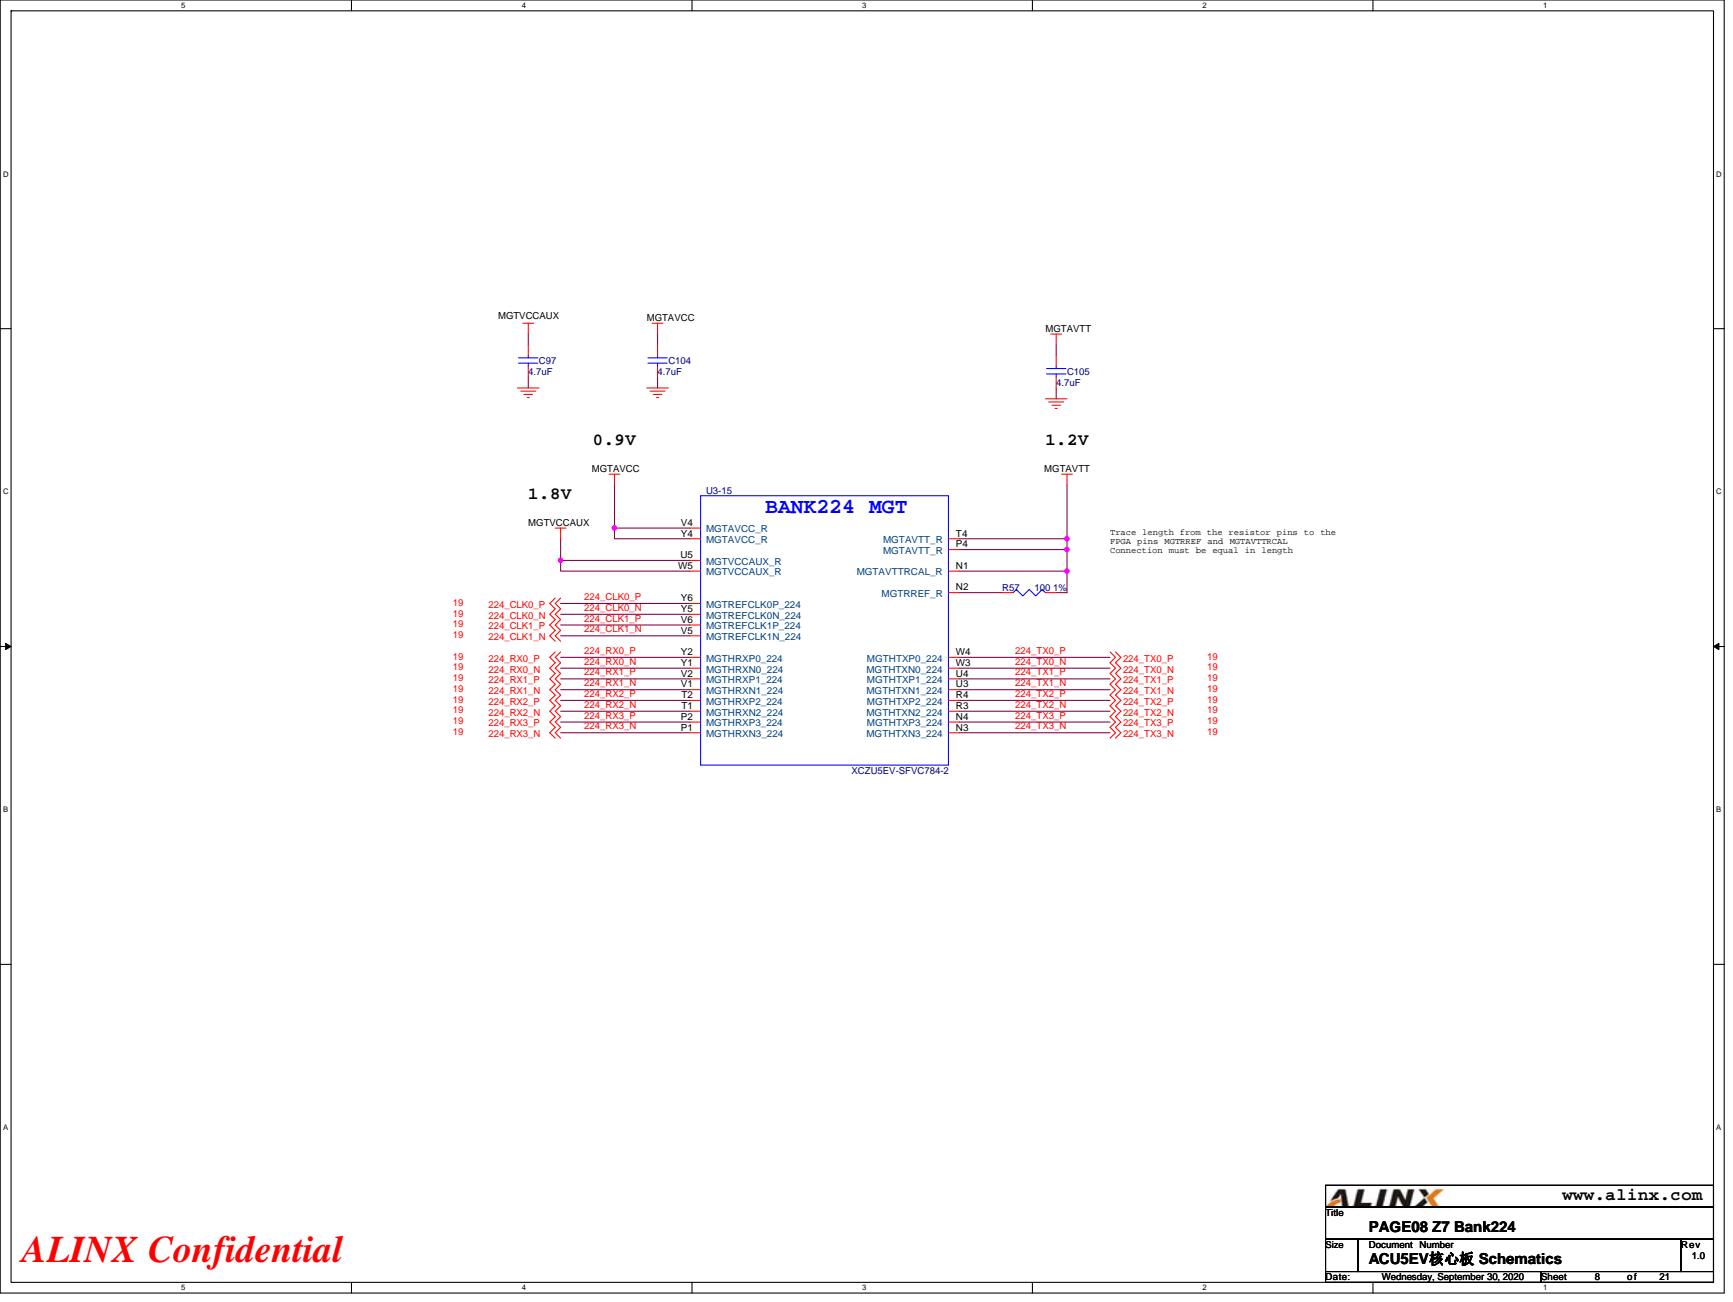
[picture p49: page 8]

Trace length from the resistor pins to the
FPGA pins MGTRREF and MGTAVTTRCAL
Connection must be equal in length

1.2V
1.2V

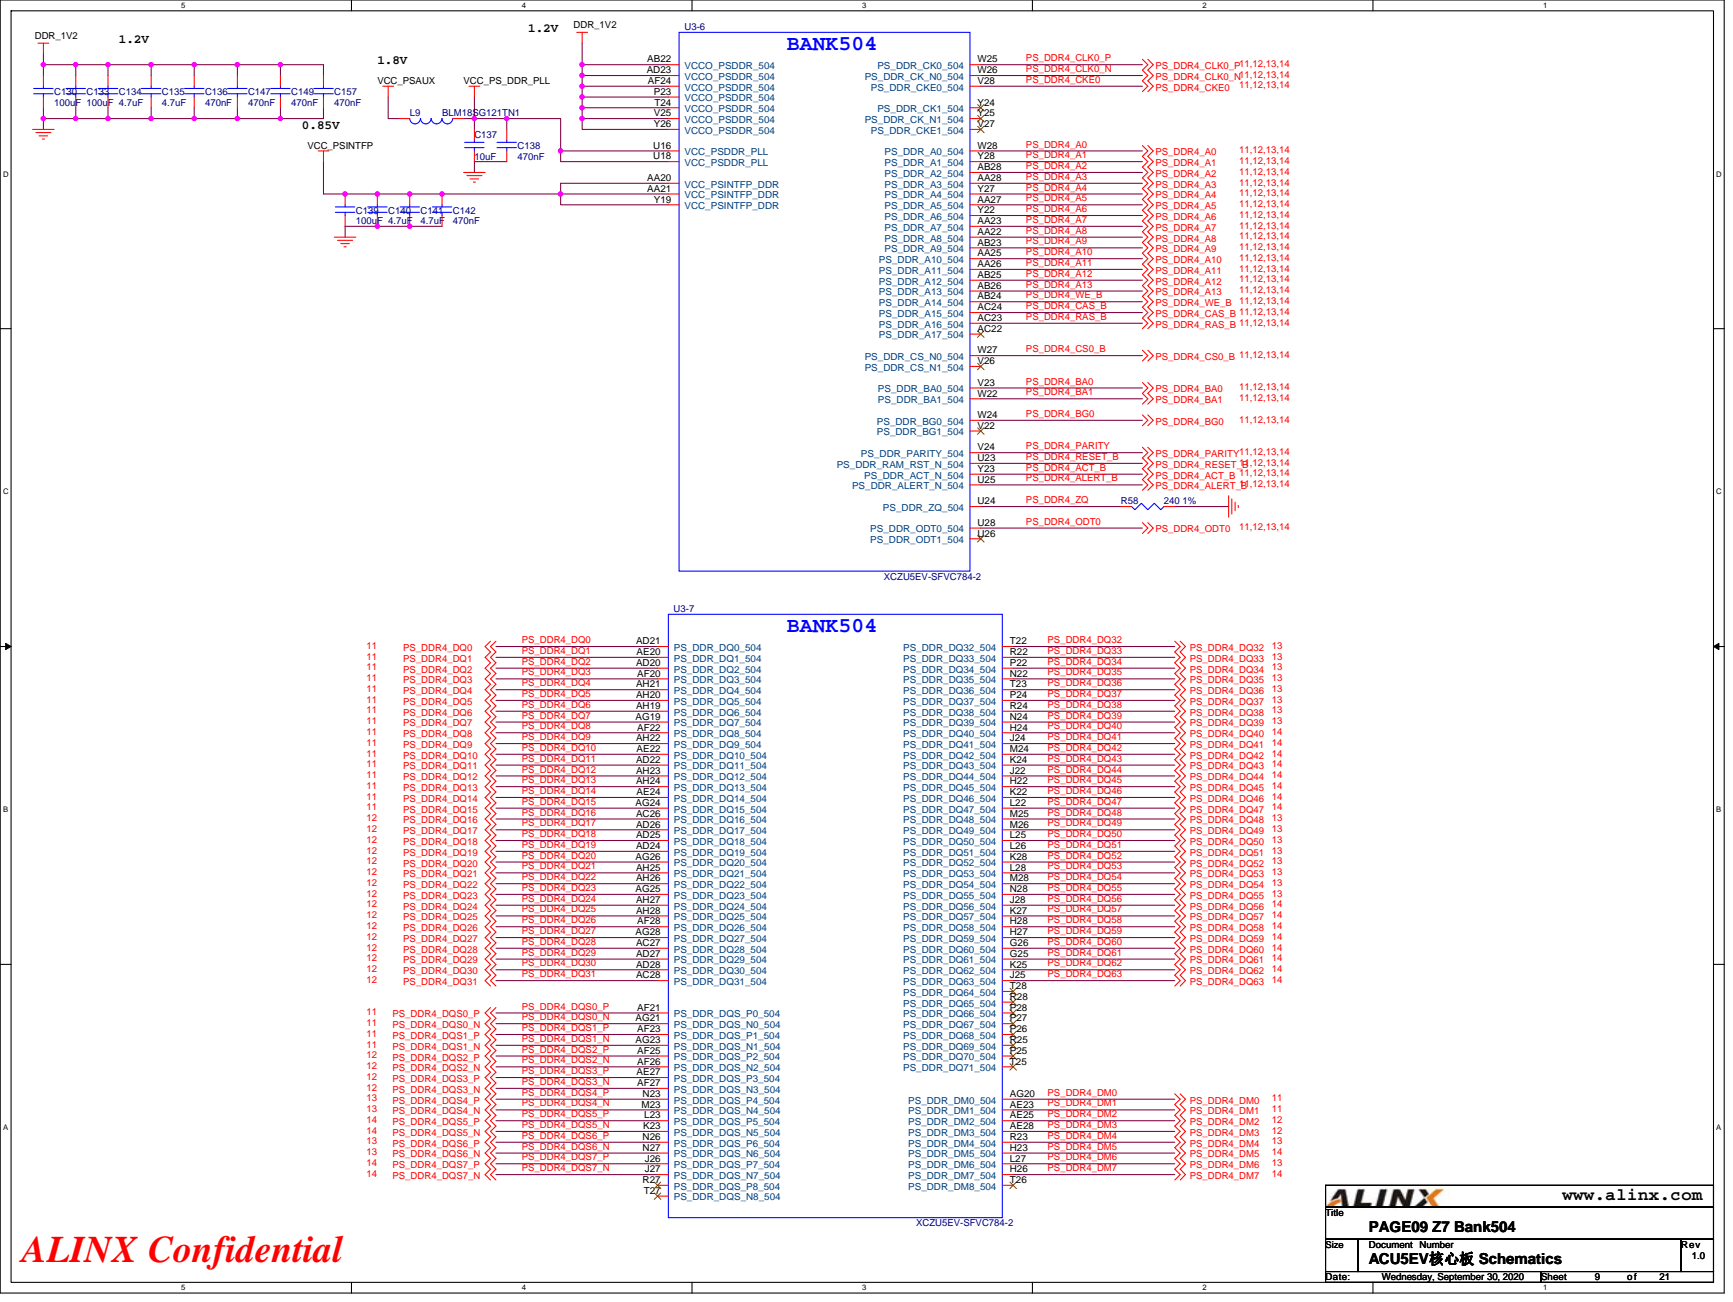
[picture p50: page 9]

0.85V

0.85V

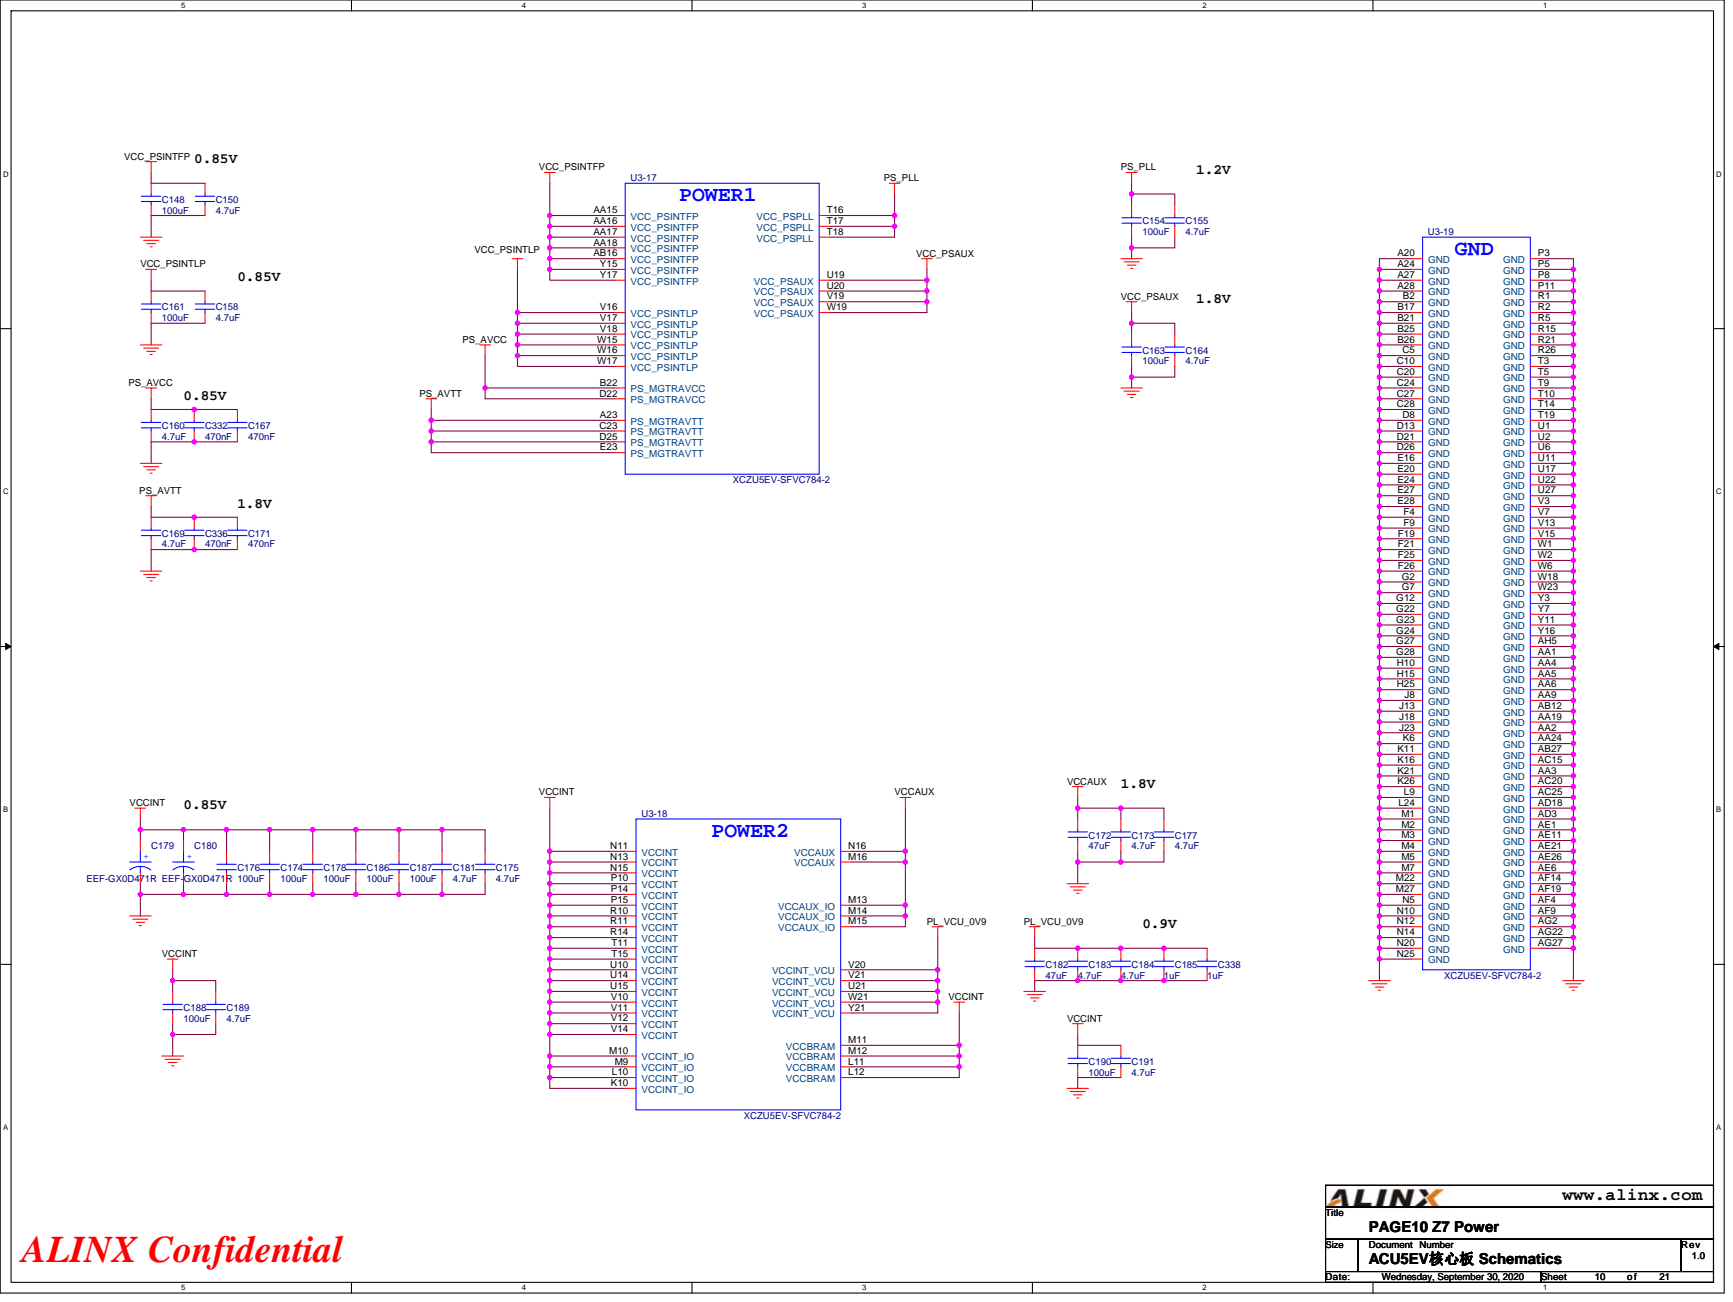
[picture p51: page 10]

1.2V

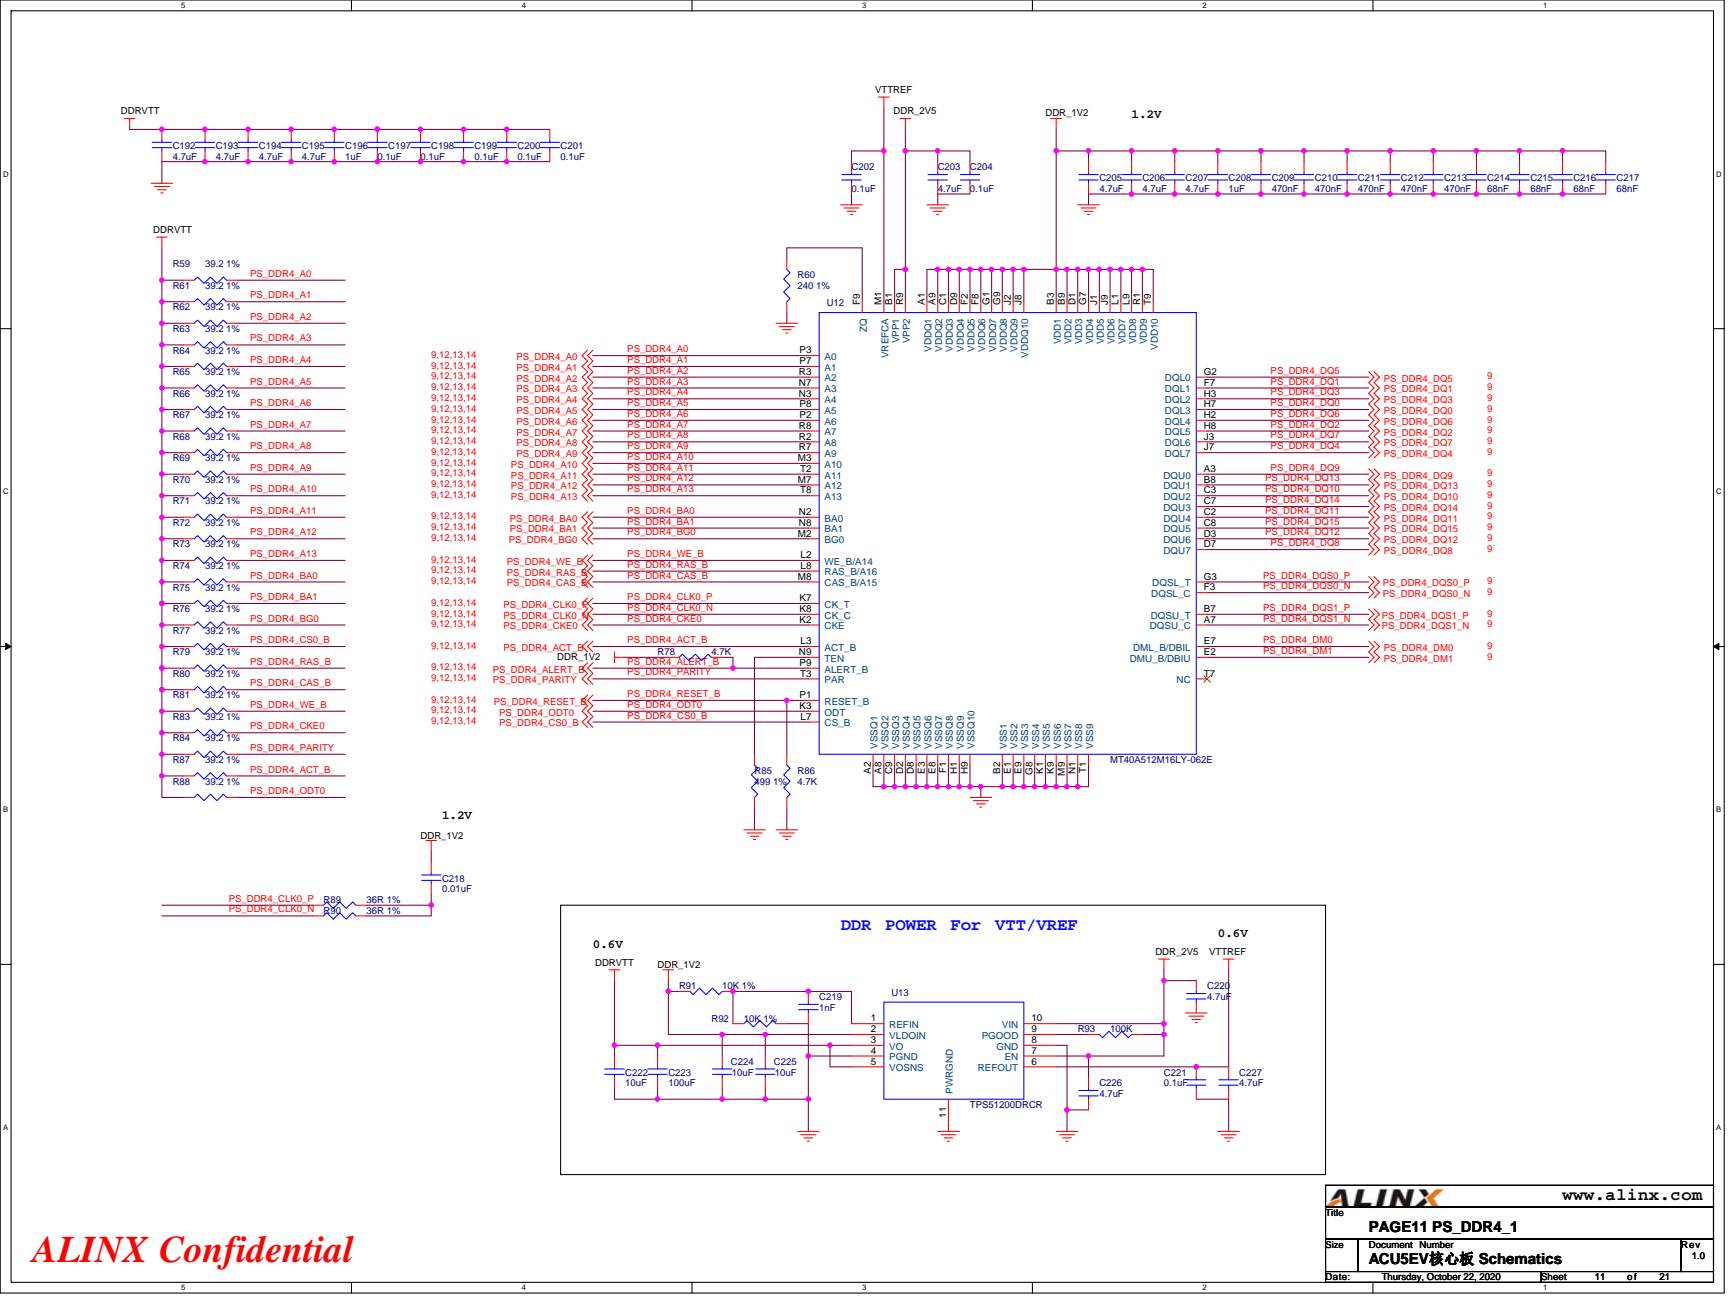
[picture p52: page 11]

1.2V

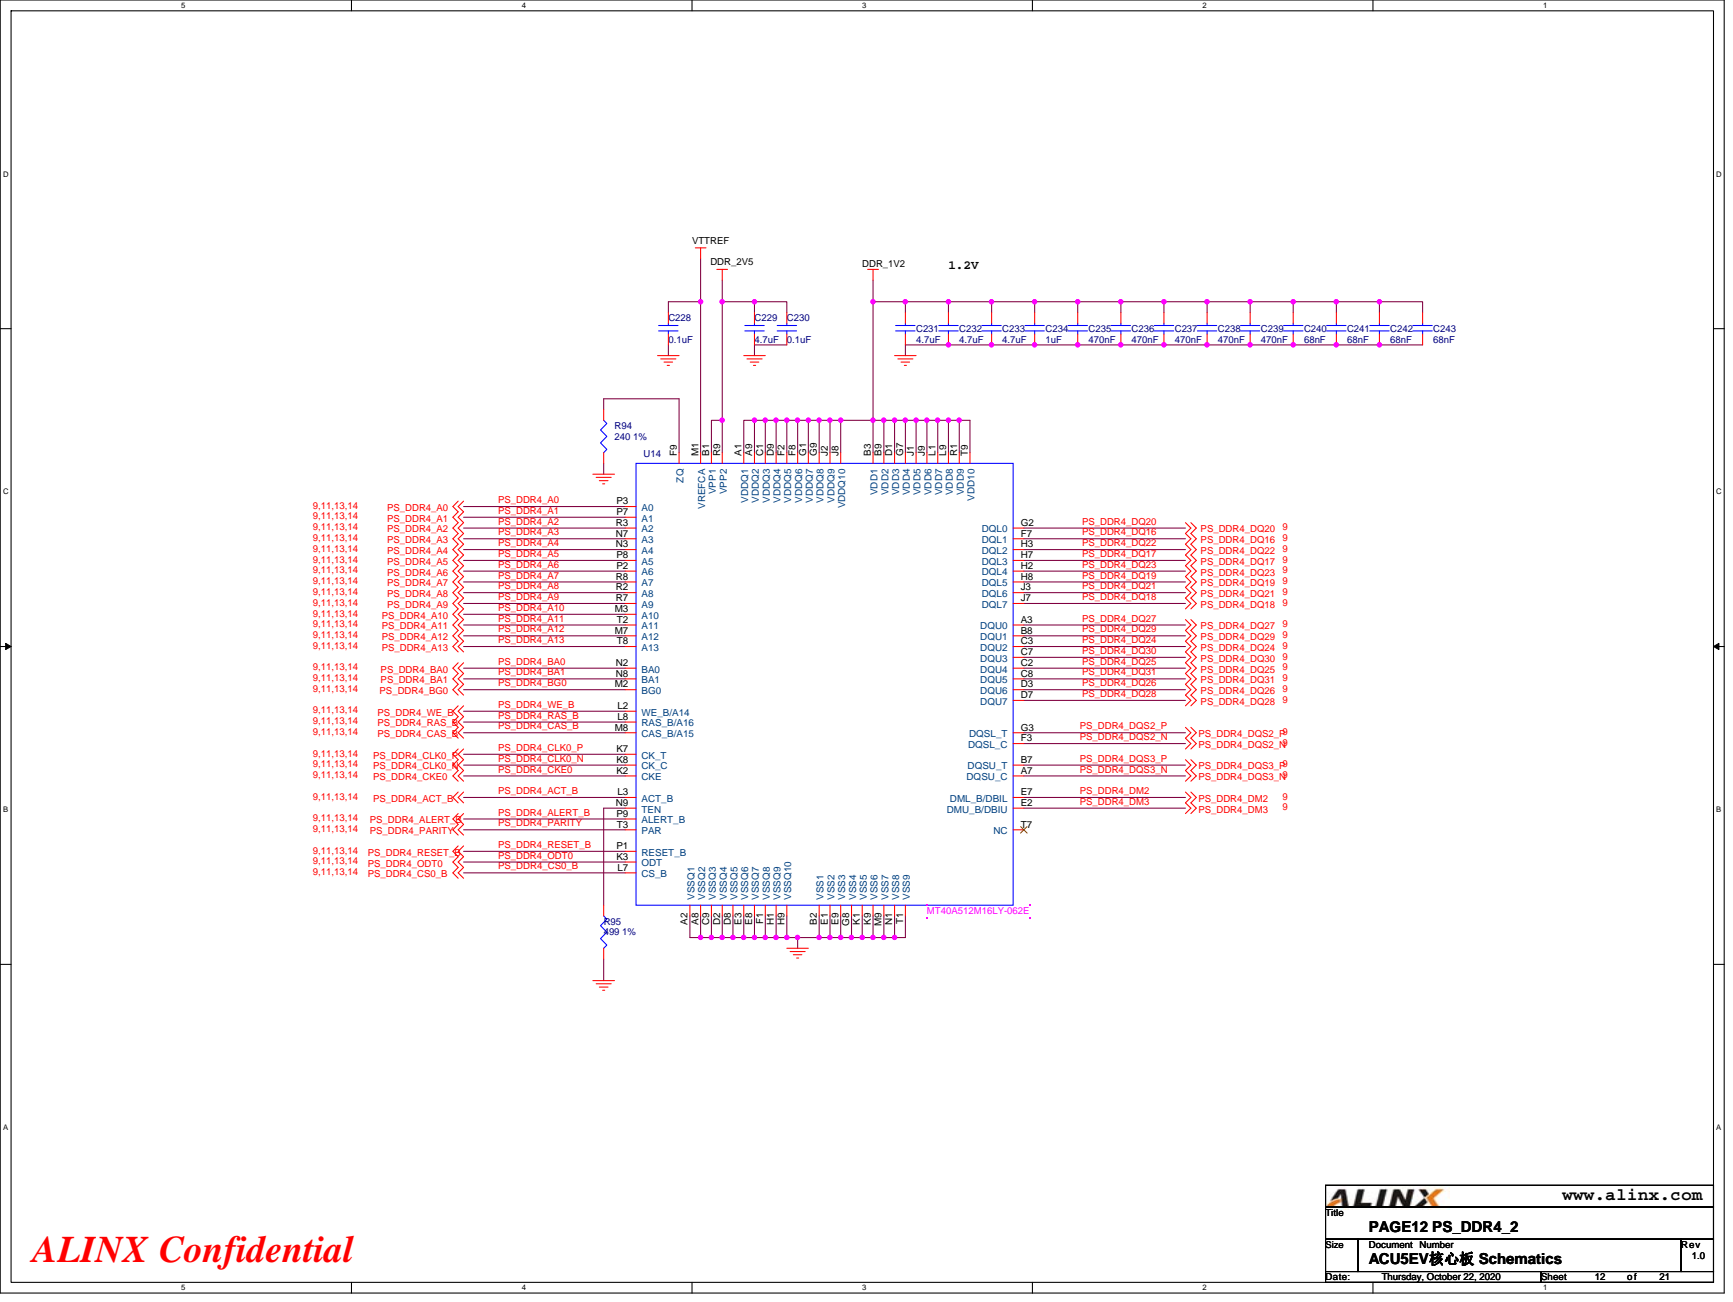
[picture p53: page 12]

1.2V


1.2V




# 200MHz

# PL SYSTEM CLOCK


BANK65, BANK66 IO Voltage can not exceed +1.8V | BANK45, BANK46 IO Voltage is +3.3V Standard

FPGA_TMS; FPGA_TCK; FPGA_TDO; FPGA_TDI; 505_CLK0_N; 505_CLK0_P; 505_CLK3_P; 505_CLK3_N; 505_CLK2_P 505_CLK2_N; 505_CLK1_P 505_CLK1_N; 505_CLK1_P; 505_CLK1_N; 505_CLK2_P; 505_CLK2_N; PAGE18 Connector_1; Wednesday, September 30, 2020; AXK5A2137YG

www.alinx.com

BANK43, BANK44 IO Voltage is +3.3V Standard | The MIO Voltage is +1.8V Standard


109 | 110
111 | 112

118
120

VCCO_65 VCCO_66 Power supply can not exceed 1.8V

POWER ON: VCCINT/VCCINT_IO/VCCBRAM(+0.85V)->VCCINT_VCU(+0.9V)->VCCAUX/VCCAUX_IO(+1.8V)->VCCO(+3.3V, +1.8V)

# POWER ON: VCCINT(+0.85V)->MGTAVCC(+09V)->MGTAVTT(+1.2V)


# GPO1-----BUCK1_2_PG GPO4-----BUCK4_PG


PS_AVTT | | LDOA1 9

PS_AVCC | VTT 47 | | 0.1uF | 10uF

VREF 53

3V3_LDO | | LDO3P3 54

LDO5P0 56 | R388 2.37K 1%

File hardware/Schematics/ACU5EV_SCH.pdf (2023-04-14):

ALINX Confidential; Title; PAGE01 Block diagram

www.alinx.com

Size | Document Number ACU5EV核心板 Schematics | Rev 1.0

Date: Wednesday, September 30, 2020 Wednesday, September 30, 2020 Wednesday, September 30, 2020 | Sheet 1 1 1 of 21 21 21

# MODE[3:0]

0000 | PS JTAG | PS JTAG Interface


0001 | Quad_SPI(24b) | 24-Bit addresssing(QSPI24)
0010 | Quad_SPI(32b) | 32-Bit addresssing(QSPI32)
0011 | SD0(2.0) | SD2.0
0100 | NAND | Requires 8-bit data bus width
0101 | SD1(2.0) | SD2.0
0110 0111 | eMMC(1.8V) USB0(2.0) | eMMC version 4.5 at 1.8V USB 2.0 only

1000 | PJTAG(MIO #0) | PJTAG connection 0 option
1001 | PJTAG(MIO #1) | PJTAG connection 1 option
1110 | SD1 LS(3.0) | SD 3.0

## VCC1V8

0.1uF | BANK500


# BANK43


VRP_64; PL_DDR4_A0; PL_DDR4_CLK_P PL_DDR4_CLK_N; PL_CLK0_P PL_CLK0_N; PL_CLK0_N; PL_CLK0_P; PL_DDR4_DM1; PL_DDR4_DQ0; PL_DDR4_DQ7 PL_DDR4_DQ6; PL_DDR4_DQS0_P; PL_DDR4_DQ1; PL_DDR4_DQS0_N; PL_DDR4_DQ2; PL_DDR4_DQ5 PL_DDR4_DQ4; PL_DDR4_DQ3; PL_DDR4_DM0; PL_DDR4_DQ15 PL_DDR4_DQ14 PL_DDR4_DQ13 PL_DDR4_DQ12; PL_DDR4_DQ11 PL_DDR4_DQ10 PL_DDR4_DQ9 PL_DDR4_DQ8; PL_DDR4_DQS1_P PL_DDR4_DQS1_N; PL_DDR4_OTD; PL_DDR4_A6; PL_DDR4_BA1; PL_DDR4_A9; PL_DDR4_A5; PL_DDR4_CS_B; PL_DDR4_BA0; PL_DDR4_A13 PL_DDR4_A7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

www.alinx.com

# BANK65


# BANK505 PS MGT



Trace length from the resistor pins to the
FPGA pins MGTRREF and MGTAVTTRCAL
Connection must be equal in length

1.2V
1.2V


0.85V

0.85V


1.2V


1.2V


1.2V


1.2V




# 200MHz

# PL SYSTEM CLOCK


BANK65, BANK66 IO Voltage can not exceed +1.8V | BANK45, BANK46 IO Voltage is +3.3V Standard

FPGA_TMS; FPGA_TCK; FPGA_TDO; FPGA_TDI; 505_CLK0_N; 505_CLK0_P; 505_CLK3_P; 505_CLK3_N; 505_CLK2_P 505_CLK2_N; 505_CLK1_P 505_CLK1_N; 505_CLK1_P; 505_CLK1_N; 505_CLK2_P; 505_CLK2_N; PAGE18 Connector_1; Wednesday, September 30, 2020; AXK5A2137YG

www.alinx.com

BANK43, BANK44 IO Voltage is +3.3V Standard | The MIO Voltage is +1.8V Standard


109 | 110
111 | 112

118
120

VCCO_65 VCCO_66 Power supply can not exceed 1.8V

POWER ON: VCCINT/VCCINT_IO/VCCBRAM(+0.85V)->VCCINT_VCU(+0.9V)->VCCAUX/VCCAUX_IO(+1.8V)->VCCO(+3.3V, +1.8V)

# POWER ON: VCCINT(+0.85V)->MGTAVCC(+09V)->MGTAVTT(+1.2V)


# GPO1-----BUCK1_2_PG GPO4-----BUCK4_PG


PS_AVTT | | LDOA1 9

PS_AVCC | VTT 47 | | 0.1uF | 10uF

VREF 53

3V3_LDO | | LDO3P3 54

LDO5P0 56 | R388 2.37K 1%

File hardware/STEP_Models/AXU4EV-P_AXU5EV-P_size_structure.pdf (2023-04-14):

200 mm


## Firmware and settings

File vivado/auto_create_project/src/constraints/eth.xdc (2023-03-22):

 
set_property PACKAGE_PIN A6 [get_ports {mdio_mdc                    }] 
set_property PACKAGE_PIN C8 [get_ports {mdio_mdio_io            }] 
set_property PACKAGE_PIN D5 [get_ports {phy_reset_n                  }] 
set_property PACKAGE_PIN E5 [get_ports {rgmii_rxc                  }] 
set_property PACKAGE_PIN B8 [get_ports {rgmii_rx_ctl            }] 
set_property PACKAGE_PIN A5 [get_ports {rgmii_rd[0]              }] 
set_property PACKAGE_PIN B5 [get_ports {rgmii_rd[1]              }] 
set_property PACKAGE_PIN F8 [get_ports {rgmii_rd[2]              }] 
set_property PACKAGE_PIN C9 [get_ports {rgmii_rd[3]              }] 
set_property PACKAGE_PIN A7 [get_ports {rgmii_txc                  }] 
set_property PACKAGE_PIN B9 [get_ports {rgmii_tx_ctl            }] 
set_property PACKAGE_PIN E9 [get_ports {rgmii_td[0]              }] 
set_property PACKAGE_PIN D9 [get_ports {rgmii_td[1]              }] 
set_property PACKAGE_PIN A9 [get_ports {rgmii_td[2]              }] 
set_property PACKAGE_PIN A8 [get_ports {rgmii_td[3]              }] 
 
set_property IOSTANDARD LVCMOS18 [get_ports {mdio_mdc                    }] 
set_property IOSTANDARD LVCMOS18 [get_ports {mdio_mdio_io            }] 
set_property IOSTANDARD LVCMOS18 [get_ports {phy_reset_n                  }] 
set_property IOSTANDARD LVCMOS18 [get_ports {rgmii_rxc                  }] 
set_property IOSTANDARD LVCMOS18 [get_ports {rgmii_rx_ctl            }] 
set_property IOSTANDARD LVCMOS18 [get_ports {rgmii_rd[0]              }] 
set_property IOSTANDARD LVCMOS18 [get_ports {rgmii_rd[1]              }] 
set_property IOSTANDARD LVCMOS18 [get_ports {rgmii_rd[2]              }] 
set_property IOSTANDARD LVCMOS18 [get_ports {rgmii_rd[3]              }] 
set_property IOSTANDARD LVCMOS18 [get_ports {rgmii_txc                  }] 
set_property IOSTANDARD LVCMOS18 [get_ports {rgmii_tx_ctl            }] 
set_property IOSTANDARD LVCMOS18 [get_ports {rgmii_td[0]              }] 
set_property IOSTANDARD LVCMOS18 [get_ports {rgmii_td[1]              }] 
set_property IOSTANDARD LVCMOS18 [get_ports {rgmii_td[2]              }] 
set_property IOSTANDARD LVCMOS18 [get_ports {rgmii_td[3]              }] 

set_property UNAVAILABLE_DURING_CALIBRATION TRUE [get_ports mdio_mdio_io]


#idelay
set_property DELAY_VALUE 500 [get_cells design_1_i/axi_ethernet_0/inst/mac/inst/tri_mode_ethernet_mac_i/rgmii_interface/delay_rgmii_rx_ctl]
set_property DELAY_VALUE 500 [get_cells {design_1_i/axi_ethernet_0/inst/mac/inst/tri_mode_ethernet_mac_i/rgmii_interface/rxdata_bus[0].delay_rgmii_rxd}]
set_property DELAY_VALUE 500 [get_cells {design_1_i/axi_ethernet_0/inst/mac/inst/tri_mode_ethernet_mac_i/rgmii_interface/rxdata_bus[1].delay_rgmii_rxd}]
set_property DELAY_VALUE 500 [get_cells {design_1_i/axi_ethernet_0/inst/mac/inst/tri_mode_ethernet_mac_i/rgmii_interface/rxdata_bus[2].delay_rgmii_rxd}]
set_property DELAY_VALUE 500 [get_cells {design_1_i/axi_ethernet_0/inst/mac/inst/tri_mode_ethernet_mac_i/rgmii_interface/rxdata_bus[3].delay_rgmii_rxd}]

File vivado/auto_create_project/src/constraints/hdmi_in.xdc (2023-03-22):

set_property PACKAGE_PIN AB11  [get_ports hdmi_in_clk]
set_property PACKAGE_PIN Y14		 [get_ports {hdmi_in_data[0]}]
set_property PACKAGE_PIN Y13		 [get_ports {hdmi_in_data[1]}]
set_property PACKAGE_PIN AB13  [get_ports {hdmi_in_data[2]}]
set_property PACKAGE_PIN AC12  [get_ports {hdmi_in_data[3]}]
set_property PACKAGE_PIN AC14  [get_ports {hdmi_in_data[4]}]
set_property PACKAGE_PIN AC13  [get_ports {hdmi_in_data[5]}]
set_property PACKAGE_PIN AD12  [get_ports {hdmi_in_data[6]}]
set_property PACKAGE_PIN AD11  [get_ports {hdmi_in_data[7]}]
set_property PACKAGE_PIN AD15  [get_ports {hdmi_in_data[8]}]
set_property PACKAGE_PIN AD14  [get_ports {hdmi_in_data[9]}]
set_property PACKAGE_PIN AG13  [get_ports {hdmi_in_data[10]}]
set_property PACKAGE_PIN AH13  [get_ports {hdmi_in_data[11]}]
set_property PACKAGE_PIN AB9		  [get_ports {hdmi_in_data[12]}]
set_property PACKAGE_PIN AB10  [get_ports {hdmi_in_data[13]}]
set_property PACKAGE_PIN Y10		  [get_ports {hdmi_in_data[14]}]
set_property PACKAGE_PIN W10		  [get_ports {hdmi_in_data[15]}]
set_property PACKAGE_PIN W11		  [get_ports {hdmi_in_data[16]}]
set_property PACKAGE_PIN W12		  [get_ports {hdmi_in_data[17]}]
set_property PACKAGE_PIN W13		  [get_ports {hdmi_in_data[18]}]
set_property PACKAGE_PIN W14		  [get_ports {hdmi_in_data[19]}]
set_property PACKAGE_PIN AB15  [get_ports {hdmi_in_data[20]}]
set_property PACKAGE_PIN AB14  [get_ports {hdmi_in_data[21]}]
set_property PACKAGE_PIN AG11  [get_ports {hdmi_in_data[22]}]
set_property PACKAGE_PIN AF11  [get_ports {hdmi_in_data[23]}]
set_property PACKAGE_PIN AA13   [get_ports hdmi_in_de]
set_property PACKAGE_PIN AA12   [get_ports hdmi_in_hs]
set_property PACKAGE_PIN AD10   [get_ports {hdmi_rstn_tri_o[0]}]
set_property PACKAGE_PIN Y12		   [get_ports hdmi_in_vs]


set_property PACKAGE_PIN AF12 [get_ports hdmi_in_i2c_scl_io]
set_property PACKAGE_PIN AE12 [get_ports hdmi_in_i2c_sda_io]

set_property IOSTANDARD LVCMOS33 [get_ports hdmi_in_i2c_scl_io]
set_property IOSTANDARD LVCMOS33 [get_ports hdmi_in_i2c_sda_io]


set_property PULLUP true [get_ports hdmi_in_i2c_scl_io]
set_property PULLUP true [get_ports hdmi_in_i2c_sda_io]


set_property PACKAGE_PIN F10   [get_ports {edid_scl}]
set_property PACKAGE_PIN G11   [get_ports {edid_sda}]
set_property PACKAGE_PIN E8   [get_ports {hpd[0]}]

set_property IOSTANDARD LVCMOS33 [get_ports {edid_scl}]
set_property IOSTANDARD LVCMOS33 [get_ports {edid_sda}]
set_property IOSTANDARD LVCMOS18 [get_ports {hpd[0]}]

set_property IOSTANDARD LVCMOS33 [get_ports hdmi_in_clk]
set_property IOSTANDARD LVCMOS33 [get_ports {hdmi_in_data[*]}]
set_property IOSTANDARD LVCMOS33 [get_ports hdmi_in_de]
set_property IOSTANDARD LVCMOS33 [get_ports hdmi_in_hs]
set_property IOSTANDARD LVCMOS33 [get_ports hdmi_in_vs]
set_property IOSTANDARD LVCMOS33 [get_ports {hdmi_rstn_tri_o[0]}]



set_property IOB TRUE [get_ports {hdmi_in_data[*]}]
set_property IOB TRUE [get_ports hdmi_in_de]
set_property IOB TRUE [get_ports hdmi_in_hs]
set_property IOB TRUE [get_ports hdmi_in_vs]

set_property DRIVE 12 [get_ports {hdmi_in_data[*]}]
set_property DRIVE 12 [get_ports hdmi_in_clk]
set_property DRIVE 12 [get_ports hdmi_in_de]
set_property DRIVE 12 [get_ports hdmi_in_hs]

create_clock -period 6.734 -name hdmi_in_clk -waveform {0.000 3.367} [get_ports hdmi_in_clk]
set_input_delay -clock [get_clocks hdmi_in_clk] -min -add_delay 2.500 [get_ports {hdmi_in_data[*]}]
set_input_delay -clock [get_clocks hdmi_in_clk] -max -add_delay 3.500 [get_ports {hdmi_in_data[*]}]
set_input_delay -clock [get_clocks hdmi_in_clk] -min -add_delay 2.500 [get_ports hdmi_in_de]
set_input_delay -clock [get_clocks hdmi_in_clk] -max -add_delay 3.500 [get_ports hdmi_in_de]
set_input_delay -clock [get_clocks hdmi_in_clk] -min -add_delay 2.500 [get_ports hdmi_in_hs]
set_input_delay -clock [get_clocks hdmi_in_clk] -max -add_delay 3.500 [get_ports hdmi_in_hs]
set_input_delay -clock [get_clocks hdmi_in_clk] -min -add_delay 2.500 [get_ports hdmi_in_vs]
set_input_delay -clock [get_clocks hdmi_in_clk] -max -add_delay 3.500 [get_ports hdmi_in_vs]

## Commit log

2023-03-22 add linux
    [bsp.cfg, devtool-fragment.cfg]
2023-04-14 add hardware
    [AXU4EV-P_AXU5EV-P.stp]
